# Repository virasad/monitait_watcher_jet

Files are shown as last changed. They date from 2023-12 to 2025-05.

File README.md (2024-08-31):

# Monitait Watcher Jet

Watcher Jet is an industrial Hardware to capture images and signals to use for monitoring and inspection manners, there are lots of applications which can be deployed by this without any concern about the power, UPS, freeze, hang, shocks and etc.
we have been working on it whithin 4 years and try to make it as reliable as possible beside having fixed security issues [Powered by Raspberry Pi](https://www.raspberrypi.com/for-industry/powered-by/product-catalogue/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)

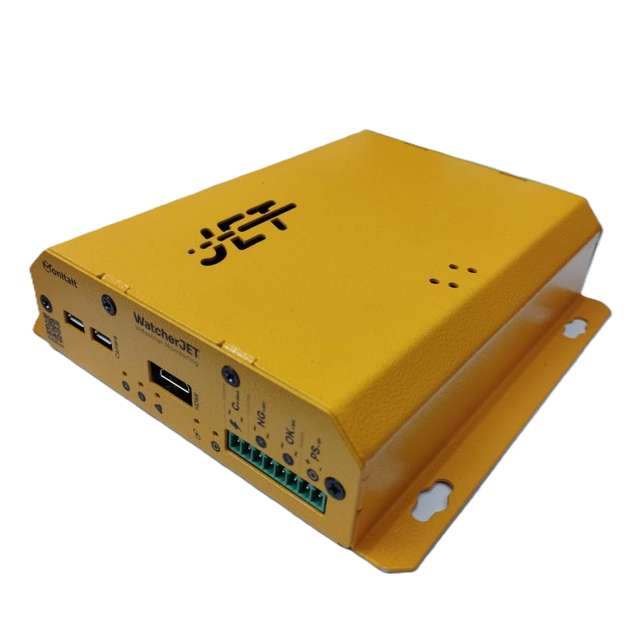
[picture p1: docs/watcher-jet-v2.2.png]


# Getting started

- if you have purchased Jet from Monitait just add it in [Watchers](https://console.monitait.com/factory/watchers) via the prepared REGISTER KEY under the box

- if you want to build watcher by youself follow the instruction in [initilize documentation](docs/README.md)

- need wiring and pinout? visit [Watcher Jet docs](https://monitait.com/docs)

- An external 12.6v 2A for `PS` (to recharge the internal battries, a regulated power is needed, polarity is important) 
- An Access Point with a SSID like: `monitait` and a password like: `p@ssword`
- Connect the Signals:
- a bipolar 12-24V digital signal for `OK`
- a bipolar 12-24V digital signal for `NG`
- a 4-20mA analog signal for `C`
- a USB camera for `CAMERA`
- a mini HDMI for `HDMI`

## Add watcher in your Monitait account

there is a register id for each watcher, add the register id in monitait console [Watchers](https://console.monitait.com/factory/watchers) tab

## Test and Deploy

- by Getting Digital Signals you should see blue indicators blink
- if the counting reached half of acceptable threshold, the warning red indicator will be turned on (in case of low battery as well)
- if the link between watcher and the server established, the red chain (link) inidactor blinks

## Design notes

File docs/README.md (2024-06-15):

# Monitait Watcher Jet

Watcher Jet is a set of an Arduino, a RaspberryPi Zero W and some Electorinc components with an internal UPS, to make sure the whole hardware and software of an Industrial monitoring application will work seamlessly



## How to initaite the RPI

- Wathcer jet heart is to make collabration between Arduino and RPI to have better data consitency
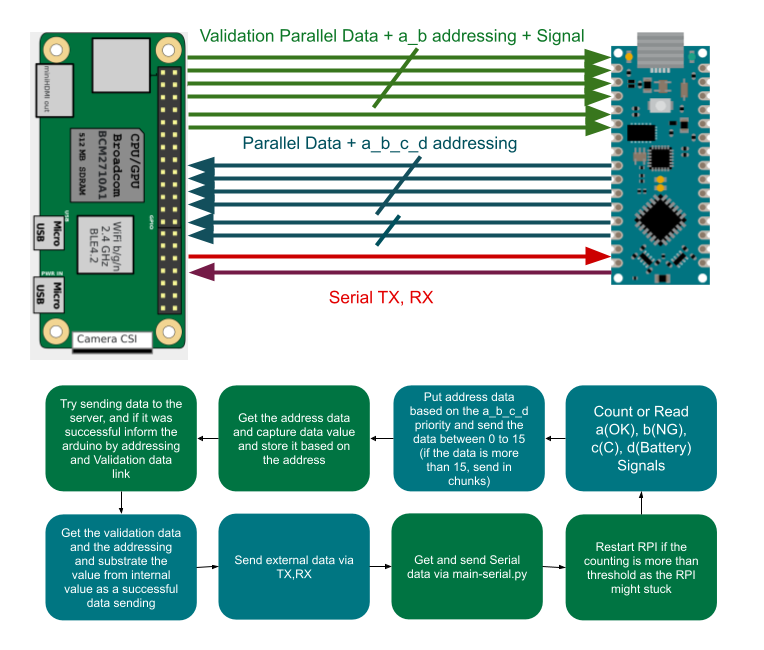
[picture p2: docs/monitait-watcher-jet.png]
monitait-watcher-jet-data-flow


- Order the PCB and the BOM of Watcher and solder all components on the board

- USE [Arduino IDE](https://www.arduino.cc/en/software) to upload the [jet-arduino](../jet-arduino/jet-arduino.ino) into the arduino board

- Install the [Raspberry Pi Imager](https://www.raspberrypi.com/software)

- Download and extract the [lite image](https://downloads.raspberrypi.com/raspios_lite_armhf/images/raspios_lite_armhf-2024-03-13/2024-03-12-raspios-bookworm-armhf-lite.img.xz)

- in the OS customisation Config page,set the name like `2024031501`(time + cronical number); set the user and password of rpi, the default user is `pi` and the default password is `raspberry`; the ssid and the password of the wireless network (i.e. `monitait` and `p@assword`) and in the SERVICES tab, enable the `SSH` (follow the instruction below)

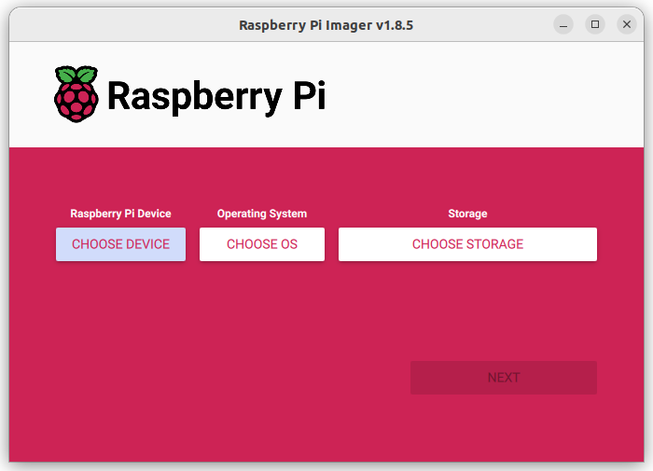
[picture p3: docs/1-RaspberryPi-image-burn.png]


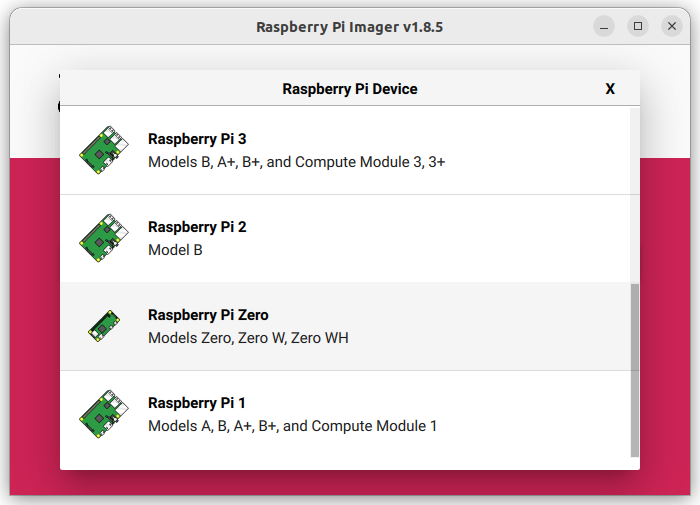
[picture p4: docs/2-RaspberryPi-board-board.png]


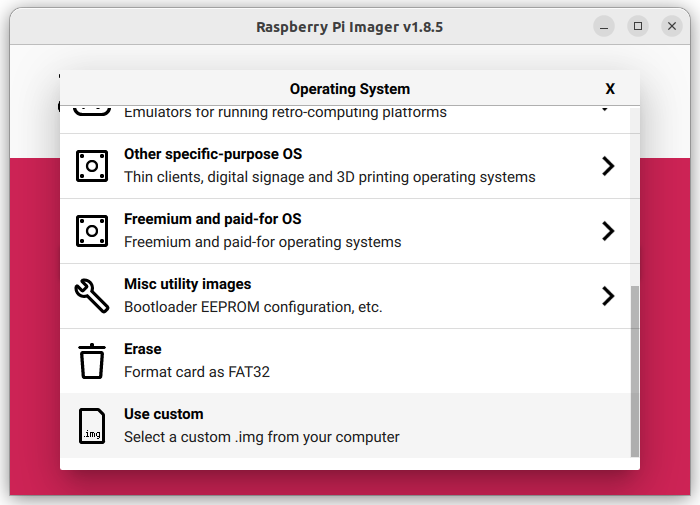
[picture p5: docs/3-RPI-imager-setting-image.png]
RPI-imager-setting


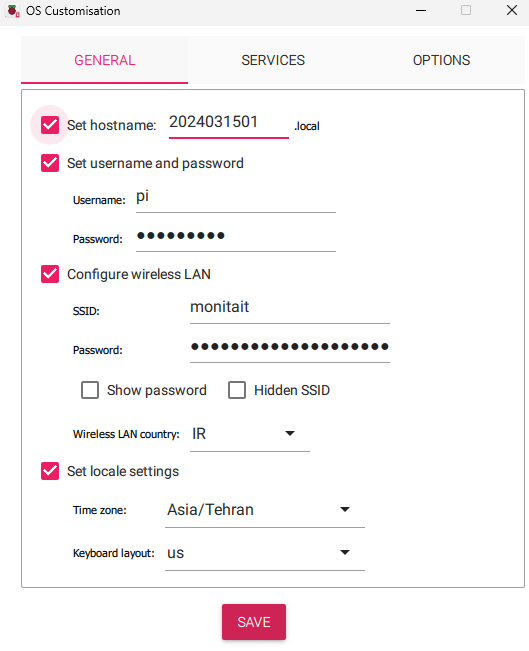
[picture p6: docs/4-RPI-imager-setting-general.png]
RPI-imager-setting


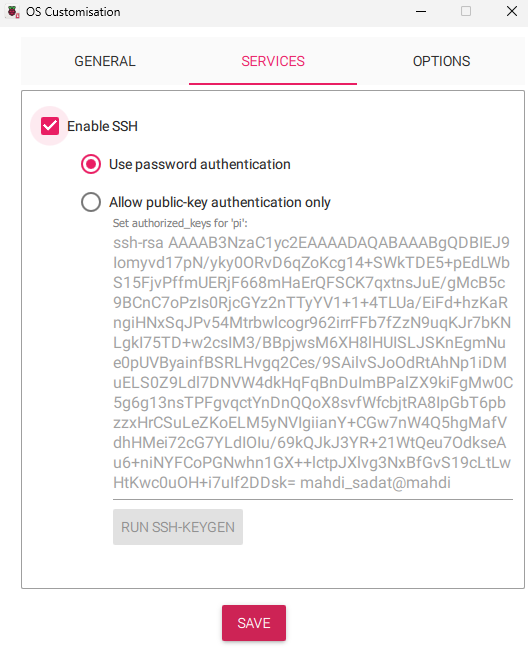
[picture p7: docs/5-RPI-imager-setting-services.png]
RPI-imager-setting


- Put the SD card in the RPI and wait for the RPI finish the setup
- ssh into rpi

`ssh pi@2024031501`

```
sudo apt-get install git -y
cd ~
git clone https://github.com/virasad/monitait_watcher_jet.git
bash /home/pi/monitait_watcher_jet/init/init.sh
sudo reboot now
```

What spare parts are needed to run on the watcher

- An SD card 
- An external 12.6v 2A for `PS` (to recharfe the internal battries, a regulated 12.6v power is needed)
- An Access Point with a SSID like: `monitait` and a password like: `p@ssword`
- a 12-24V digital signal for `OK`
- a 12-24V digital signal for `NG`
- a 4-20mA analog signal for `C`
- a USB camera for `CAMERA`
- a mini HDMI for `HDMI`

* the polarity only is important for PS

## Add watcher in your Monitait account

there is a register id for each watcher, add the register id in monitait console [Watchers](https://console.monitait.com/factory/watchers) tab

## Test and Deploy

- by sending Signals you should see blue indicators blink
- if the counting reached half of acceptable threshold, the warning red indicator will be turn on (in case of low battery as well)
- if the link between watcher and the server established, the link inidactor blinks

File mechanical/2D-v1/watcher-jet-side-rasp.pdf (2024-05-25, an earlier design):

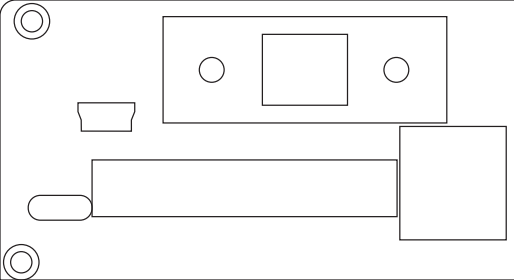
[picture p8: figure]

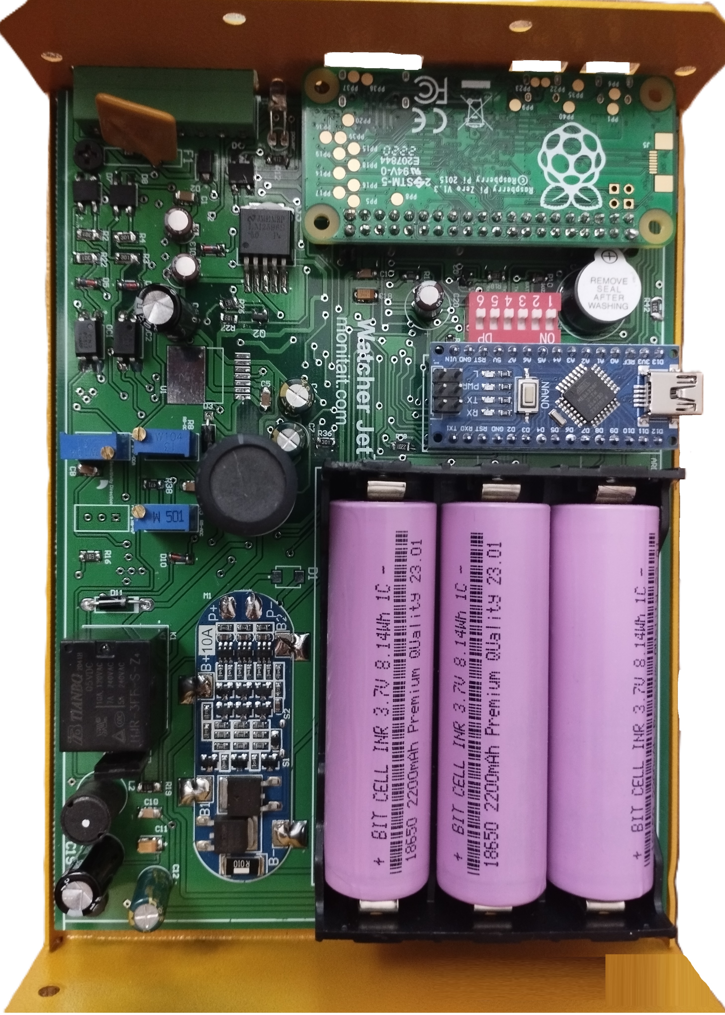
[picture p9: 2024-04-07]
docs/Jet-inside.jpg

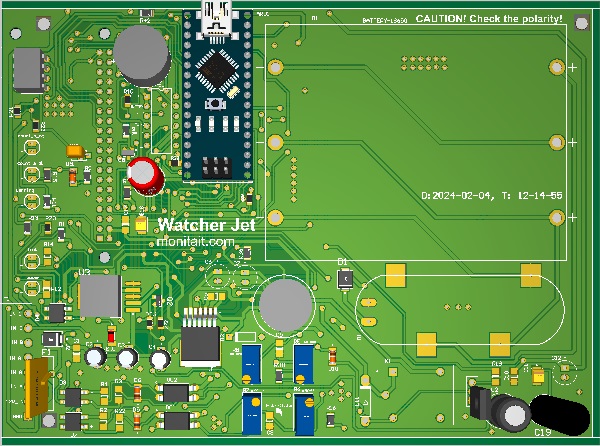
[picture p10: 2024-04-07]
pcb/PCB-v2/PCB-3D.jpg

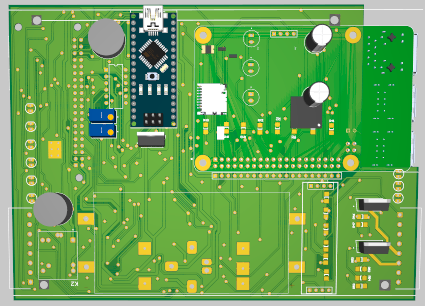
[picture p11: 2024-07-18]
pcb/Monitait_V2.png

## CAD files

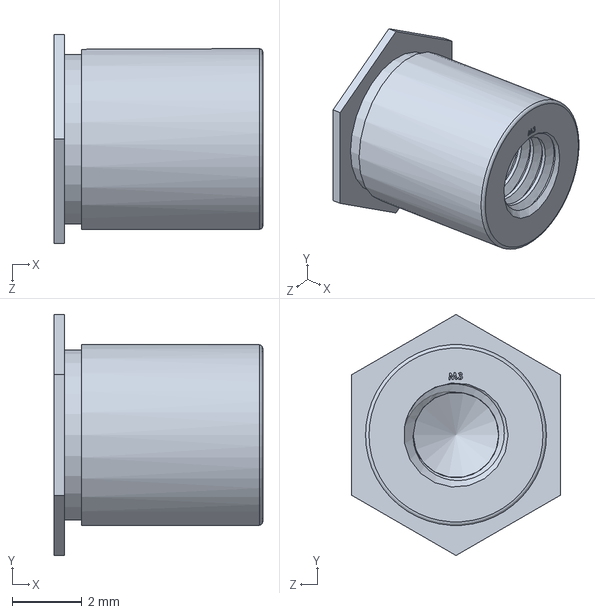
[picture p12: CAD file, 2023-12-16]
mechanical/3D-v3/M3 L6.SLDPRT
6.00 x 6.93 x 6.00 mm

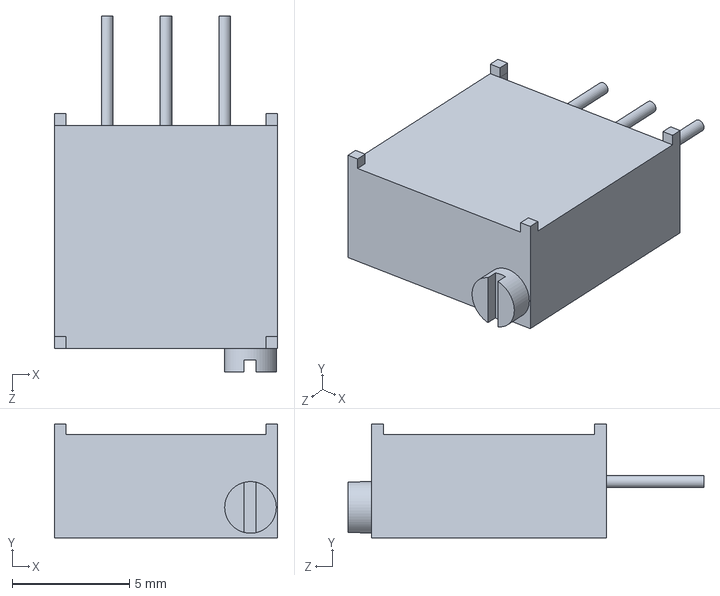
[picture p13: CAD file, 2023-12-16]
mechanical/3D-v3/Bourns-3296W.SLDPRT
9.50 x 4.85 x 15.1 mm

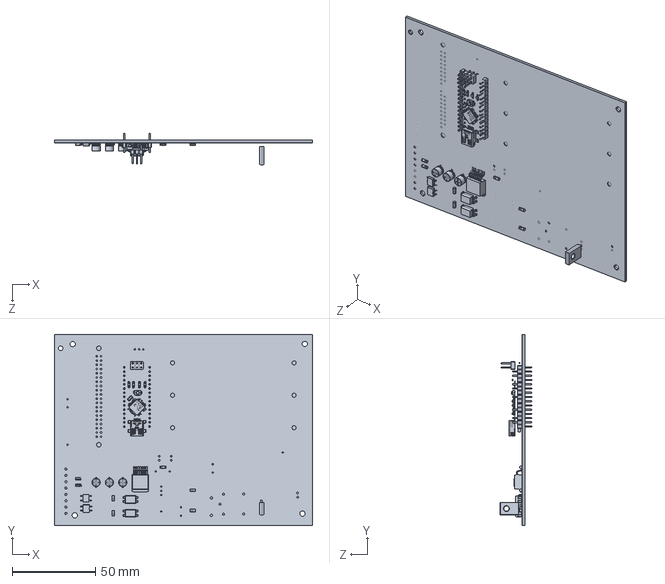
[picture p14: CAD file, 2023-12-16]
mechanical/3D-v3/Monitait_V2.SLDPRT
155.0 x 115.0 x 19.1 mm

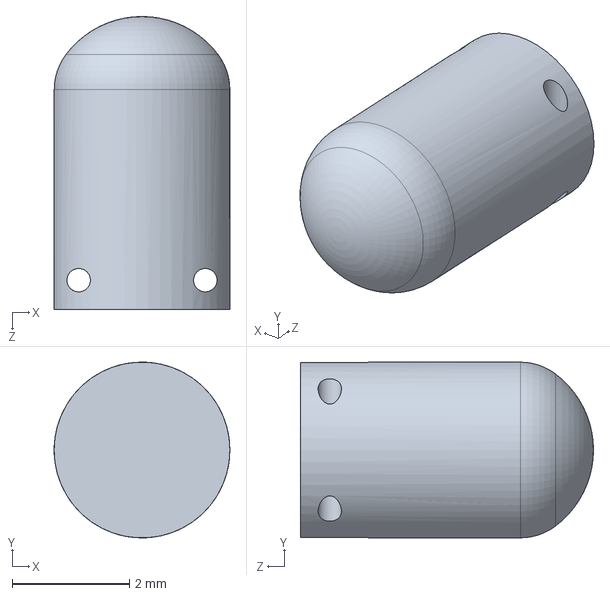
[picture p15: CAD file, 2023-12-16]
mechanical/3D-v3/LED 3.SLDPRT
3.00 x 3.00 x 5.00 mm

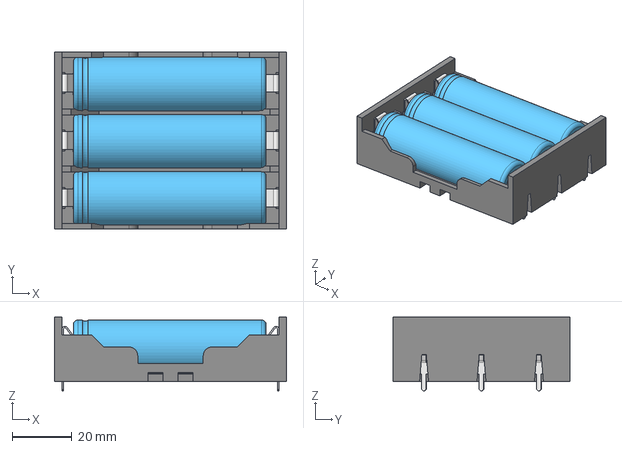
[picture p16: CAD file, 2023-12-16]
mechanical/3D-v3/3 Battery Holder With Batteries.step
78.0 x 59.6 x 24.7 mm

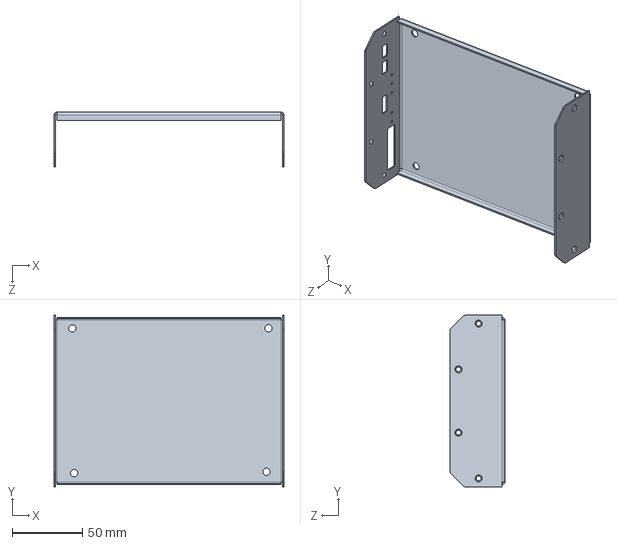
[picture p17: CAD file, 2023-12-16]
mechanical/3D-v3/Bottom Plate.SLDPRT
163.5 x 122.0 x 39.0 mm

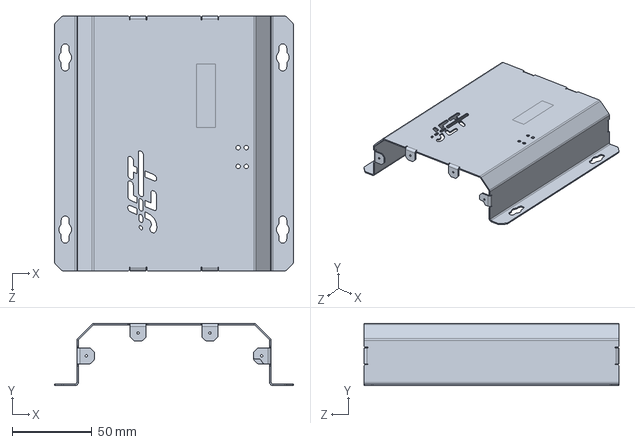
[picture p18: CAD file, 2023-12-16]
mechanical/3D-v3/Cover.SLDPRT
150.0 x 39.0 x 160.0 mm

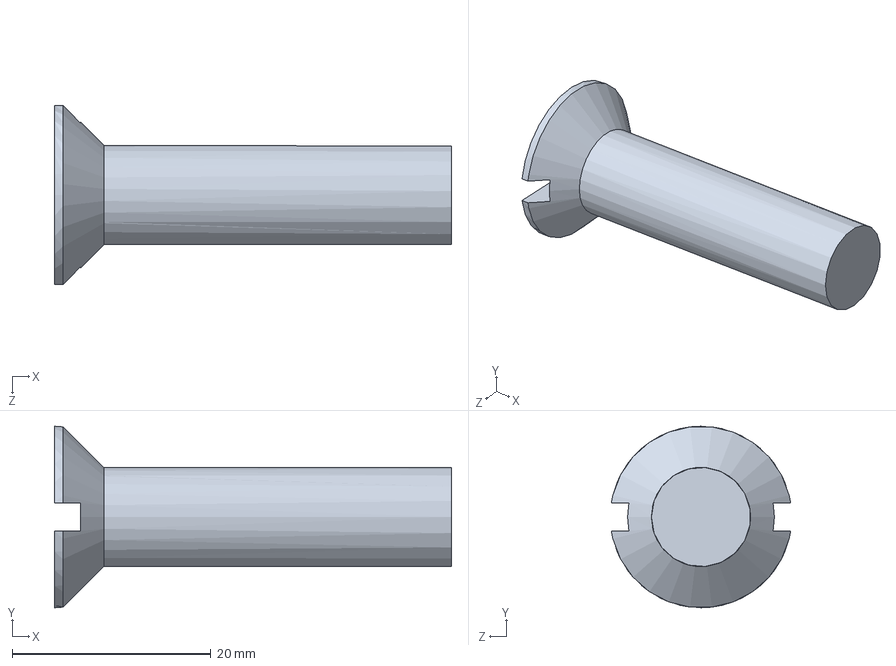
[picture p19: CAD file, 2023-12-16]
mechanical/3D-v3/flat head screw_am.sldprt
40.0 x 18.3 x 18.1 mm

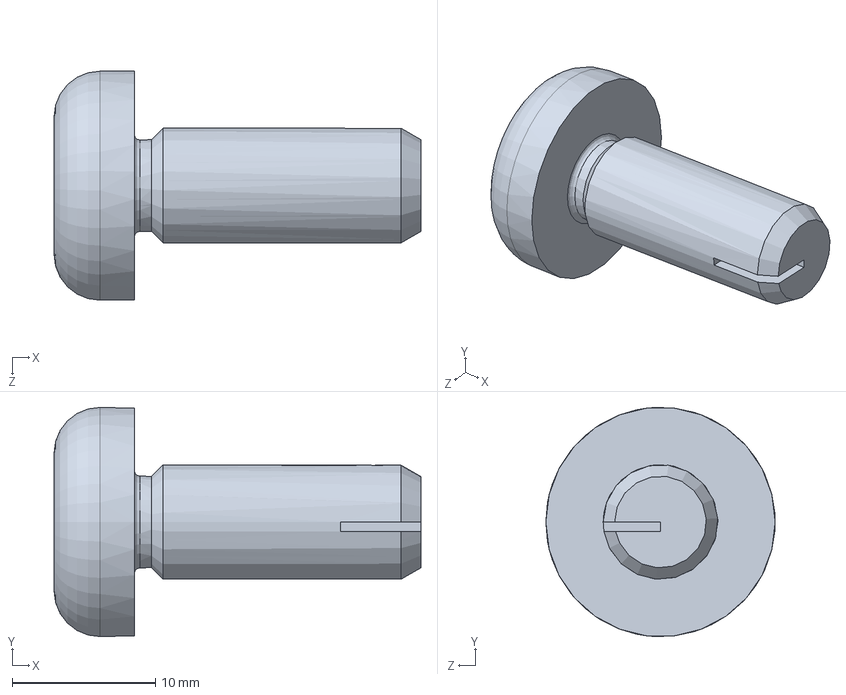
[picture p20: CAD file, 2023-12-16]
mechanical/3D-v3/pan head tapping screw_am.sldprt
25.6 x 16.0 x 16.0 mm

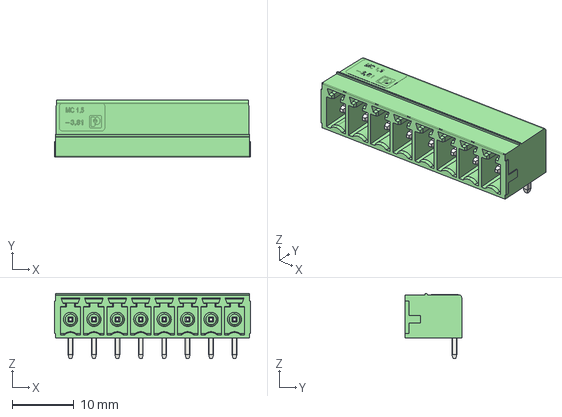
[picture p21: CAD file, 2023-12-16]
mechanical/3D-v3/1803332.stp
31.9 x 9.20 x 10.7 mm

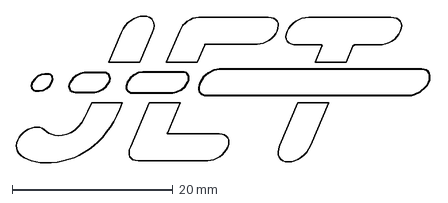
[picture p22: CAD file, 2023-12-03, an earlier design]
mechanical/2D-v1/monitait_engrave_watcher_jet_logo.dxf
51.8 x 18.3 mm

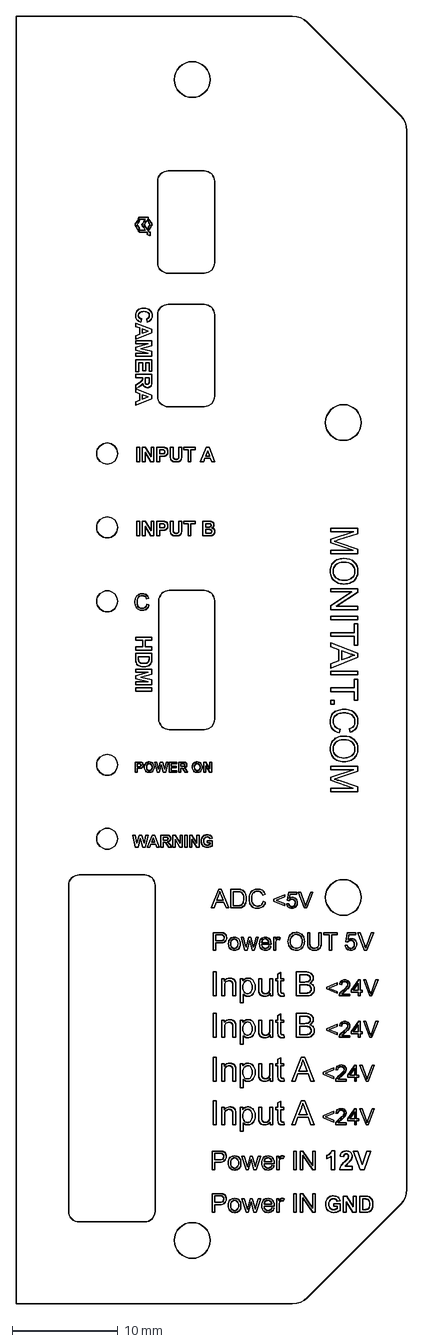
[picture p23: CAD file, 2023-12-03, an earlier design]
mechanical/2D-v2.1/jet.dxf
37.0 x 122.0 mm

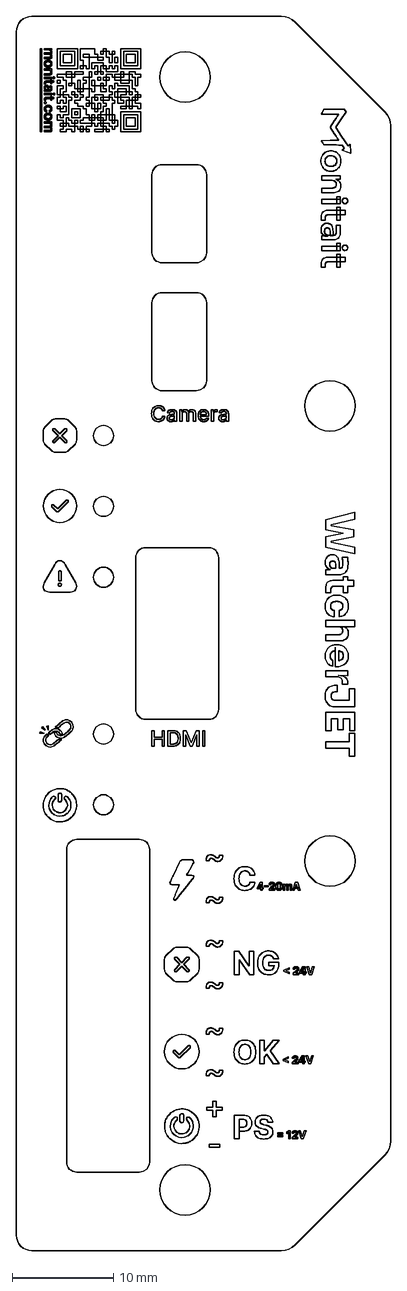
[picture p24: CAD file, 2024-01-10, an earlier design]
mechanical/2D-v2.2/watcher-jet-v2.2-side-layout.dxf
37.0 x 122.0 mm

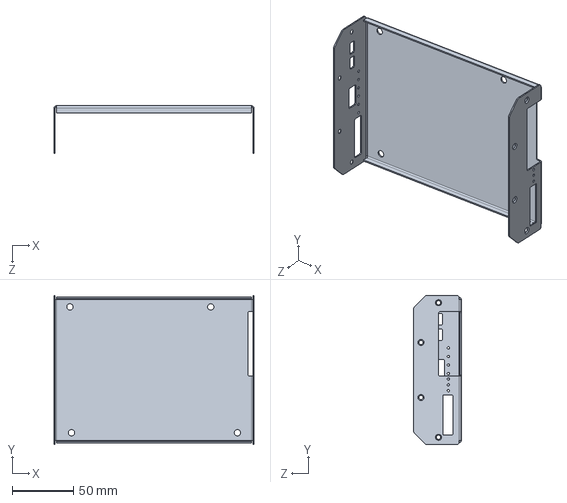
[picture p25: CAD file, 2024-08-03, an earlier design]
mechanical/3D/Bottom Plate_Ver2.SLDPRT
163.5 x 122.0 x 39.0 mm

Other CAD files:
mechanical/3D-v3/MirrorBourns-3296W.SLDPRT
mechanical/3D-v3/Logo.SLDPRT
mechanical/3D-v3/1803332.SLDPRT
mechanical/3D-v3/3 Battery Holder With Batteries.SLDPRT
mechanical/3D-v3/Watcher JET Assy.SLDDRW
mechanical/3D/Cover_Ver2.SLDPRT
mechanical/3D/Logo_Ver2.SLDPRT
mechanical/3D/countersunk flat head cross recess screw_din.sldprt

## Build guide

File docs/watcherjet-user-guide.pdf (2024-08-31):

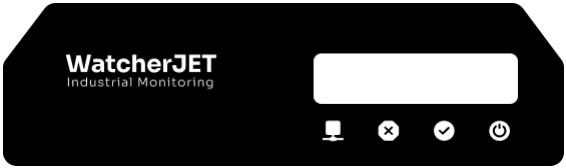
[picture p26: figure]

Step 1: | Step 2:
Connect the sensors | Connect the power supply
Step 3:
Provide an
access point
AP
Step 4:
Go to onsole.monitait.com/factory/watchers to add your watcher and get real-time feedback

# WatcherJET 3.0

# STEP-BY-STEP USER GUIDE

monitait.com | Powered by Monitait

WatcherJET 3.0

USER GUIDE
Table of Contents
Step 1: Connect the sensors
External machine signal

Mode settings for counting defects

Push button

Obstacle sensor

Encoder

Step 2: Connect the power supply

Power supply specifications

Step 3: Provide an access point

Access point setup

Step 4: Go to console.monitait.com

Software setup

Chapter 1: Collecting data

USER GUIDE
Table of Contents

Chapter 2: Taking action

Step 1: Connect the high current power supply High current power supply
Step 2: Set up the emitters

Connecting the emitters

Step 3: Connect the actuators

Ejector and warning

USER GUIDE
1
Step 1: Connect the sensors

External machine signal

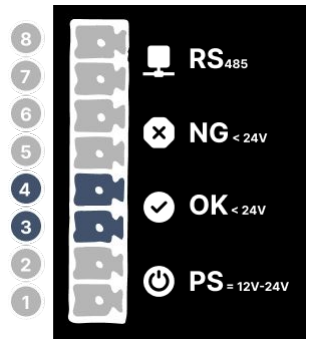
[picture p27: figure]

- Production Count

Any 1224 signal from the machine can be used as a one piece counter. Connect 2 wires from your machine to the OK inputs 3 and 4) to start counting automatically with WatcherJET.

Bidirectional signal and isolated by internal optocoupler

ejector signal, ensure that keys 3 and 4

- Counting Defects

Connect the ejector signal or the machine output to the NG inputs 5 and 6.

DATASHEET Step 1: Connect the sensors

External machine signal

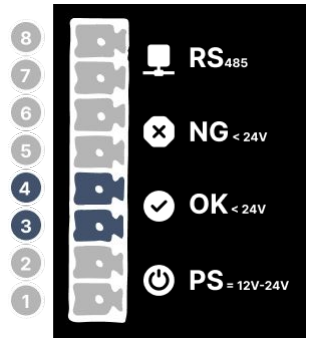
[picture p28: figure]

- Production Count

Any 1224 signal from the machine can be used as a one piece counter. Connect 2 wires from your machine to the OK inputs 3 and 4) to start counting automatically with WatcherJET.

Bidirectional signal and isolated by internal optocoupler

- Counting Defects

Connect the ejector signal or the machine output to the NG inputs 5 and 6.

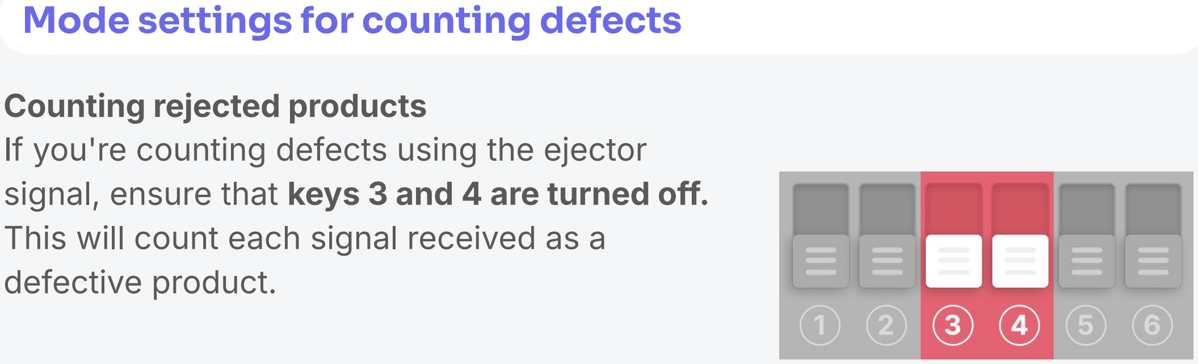
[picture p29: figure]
Counting rejected products; defective product.; Mode settings for counting defects

If you're counting defects using the ejector signal, ensure that keys 3 and 4 are turned off. This will count each signal received as a

DATASHEET Step 1: Connect the sensors

Counting remained products

If you're counting non-defective products based on the machine output signal, turn key 3 on and key 4 off. This will count the remaining products after subtracting the defective ones Total OK products minus NG products).

Push button

- Production Count

Take one wire from the push button and connect it to the OK input 4. Connect the

other wire from the same button to the negative power input 1.

Now, take a wire and connect the other OK input 3) to the positive power input 2.

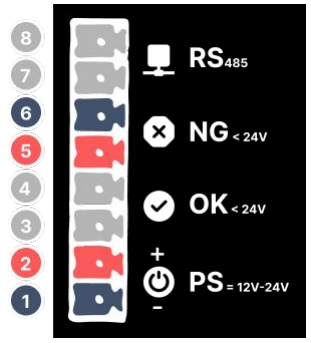
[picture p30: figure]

- Counting Defects

To count defects with a push button repeat the same steps with another push button and the NG inputs.

Take one wire from the push button and connect it to the NG input 6. Connect the other wire from the same button to the negative power input 1.

DATASHEET Step 1: Connect the sensors

Now, take a wire and connect the other NG input 5) to the positive power input 2.

Obstacle sensor

- Production Count

Take the sensor black wire and connect it to the OK input 4. Then connect the brown wire to the positive power input 2 and the blue wire to the negative power input 1.

Now, take a wire and connect the other OK input 3) to the positive power input 2.

- Counting Defects

To count defects with a obstacle sensor repeat the same steps with another sensor and the NG inputs. Then adjust the mode settings according to your counting method.

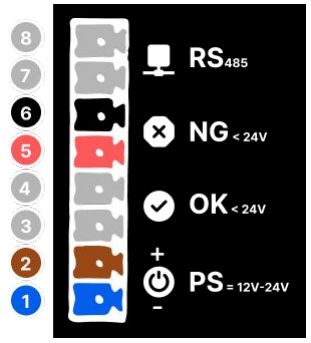
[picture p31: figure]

Take the sensor black wire and connect it to the NG input 6. Then connect the brown wire to the positive power input 2 and the blue wire to the negative power input 1.

Now, take a wire and connect the other NG input 5) to the positive power input 2.

DATASHEET Step 1: Connect the sensors

Encoder

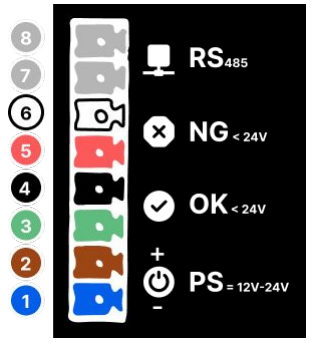
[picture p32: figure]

Take the encoder white wire and connect it to one of the NG inputs 6. Then take the black wire and connect it to the OK input 4. Now, connect the brown wire to the positive power input 2 and the blue wire to the negative power input 1.

Finally take two wires and connect the other OK input 3) and the other NG input 5) to the positive power input 2.

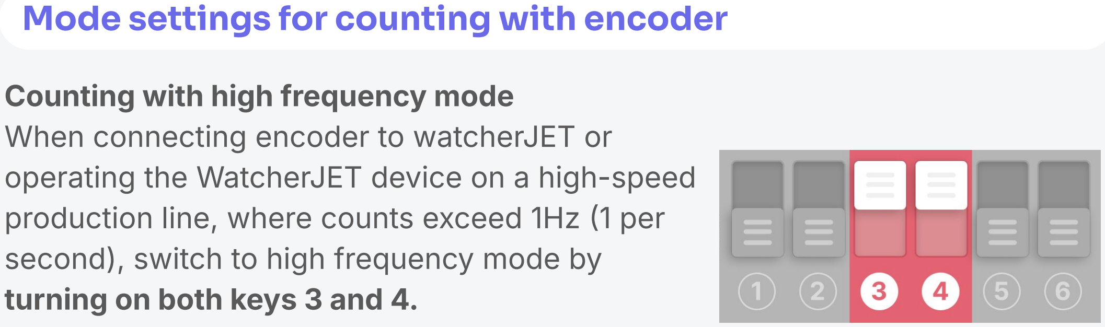
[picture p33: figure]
Counting with high frequency mode; turning on both keys 3 and 4.; Mode settings for counting with encoder

When connecting encoder to watcherJET or operating the WatcherJET device on a high-speed production line, where counts exceed 1Hz 1 per second), switch to high frequency mode by

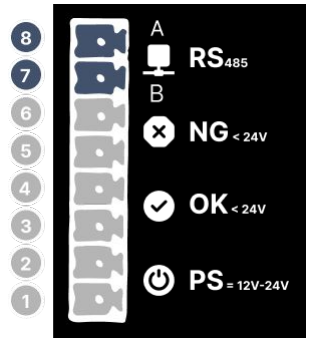
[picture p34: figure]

RS485 protocol

If you want to connect more than one sensor to your device and collect other types of data you need to use RS485 protocol. Take the A lead from your sensor and connect it to the RS485A inputs 8) then take the B lead of the sensor and connect it to the RS485B inputs 7.

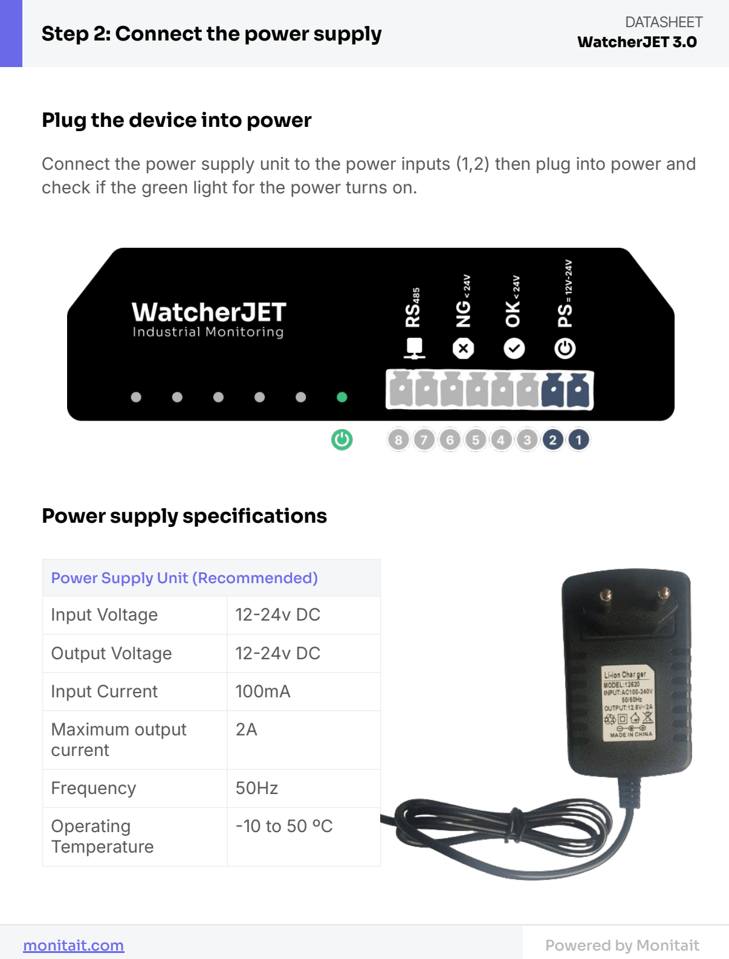
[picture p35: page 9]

DATASHEET Step 2: Connect the power supply

Plug the device into power

Power Supply Unit (Recommended)
Input Voltage | 1224v DC
Output Voltage | 1224v DC
Input Current | 100mA
Maximum output current | 2A
Frequency | 50Hz
Operating Temperature | 10 to 50 ºC

Connect the power supply unit to the power inputs 1,2) then plug into power and check if the green light for the power turns on.

Power supply specifications

DATASHEET Step 3: Provide an access point

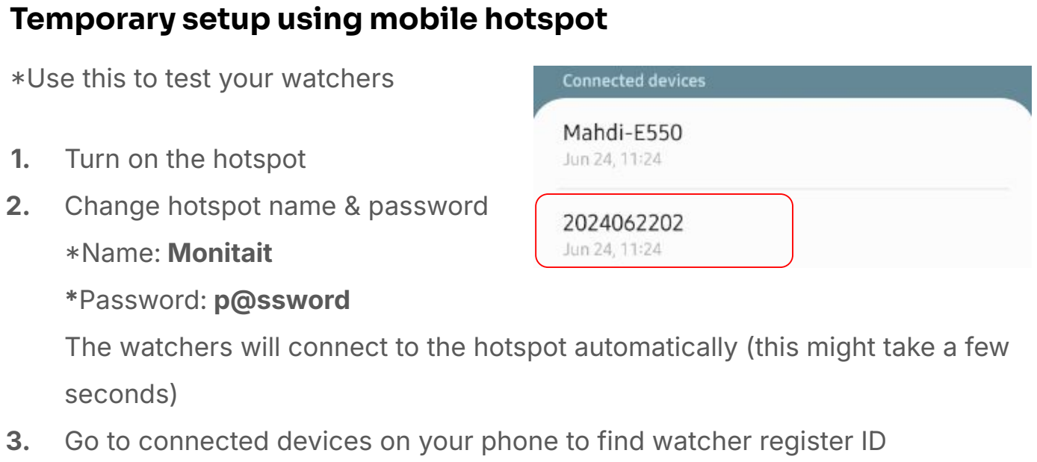
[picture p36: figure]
Temporary setup using mobile hotspot; 1. Turn on the hotspot 2. Change hotspot name & password Name: Monitait *Password: p@ssword; seconds); Use this to test your watchers

The watchers will connect to the hotspot automatically (this might take a few

### 3. Go to connected devices on your phone to find watcher register ID

Permanent setup using router

You can use any type of router you have for this step but if you are considering acquiring new ones there are three models that have been tested and completely compatible with WatcherJET system:

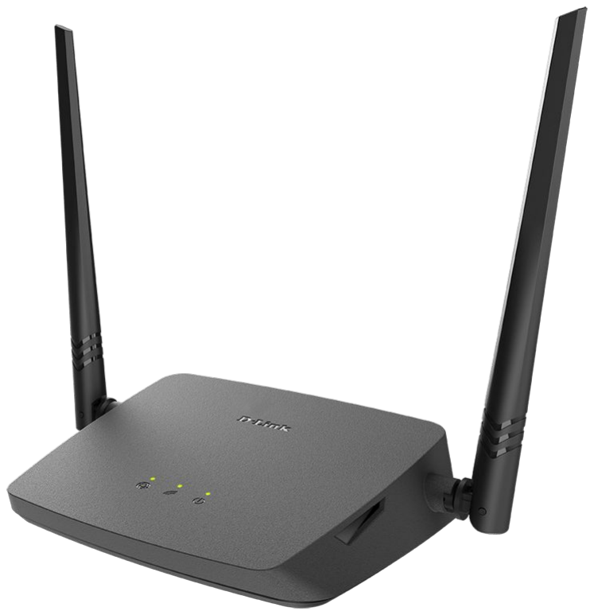
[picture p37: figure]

Tenda N301 - setup (https://www.tendacn.com/product/overview/N301.html)
DLink DIR612 - setup (https://www.dlink.com/middle-east/en/products/dir-612-wireless-n300-router)
UniFi APACLR - setup (https://dl.ubnt.com/guides/UniFi/UniFi_AP-AC-LR_QSG.pdf)

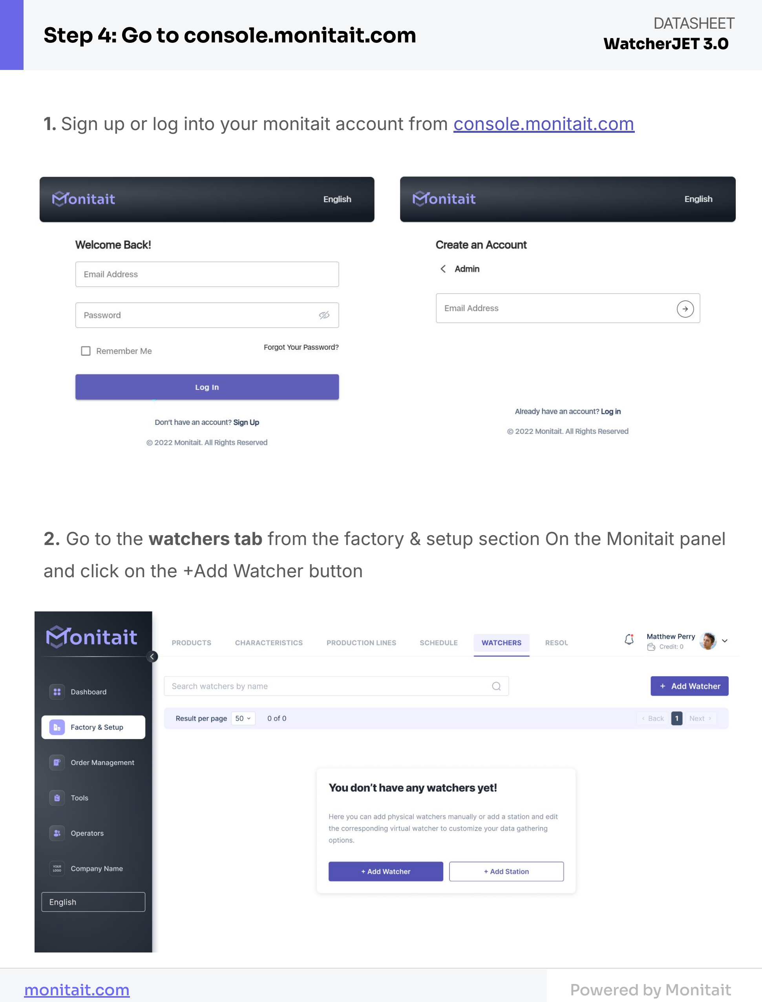
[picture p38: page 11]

DATASHEET Step 4: Go to console.monitait.com

### 1. Sign up or log into your monitait account from console.monitait.com

### 2. Go to the watchers tab from the factory & setup section On the Monitait panel

and click on the Add Watcher button

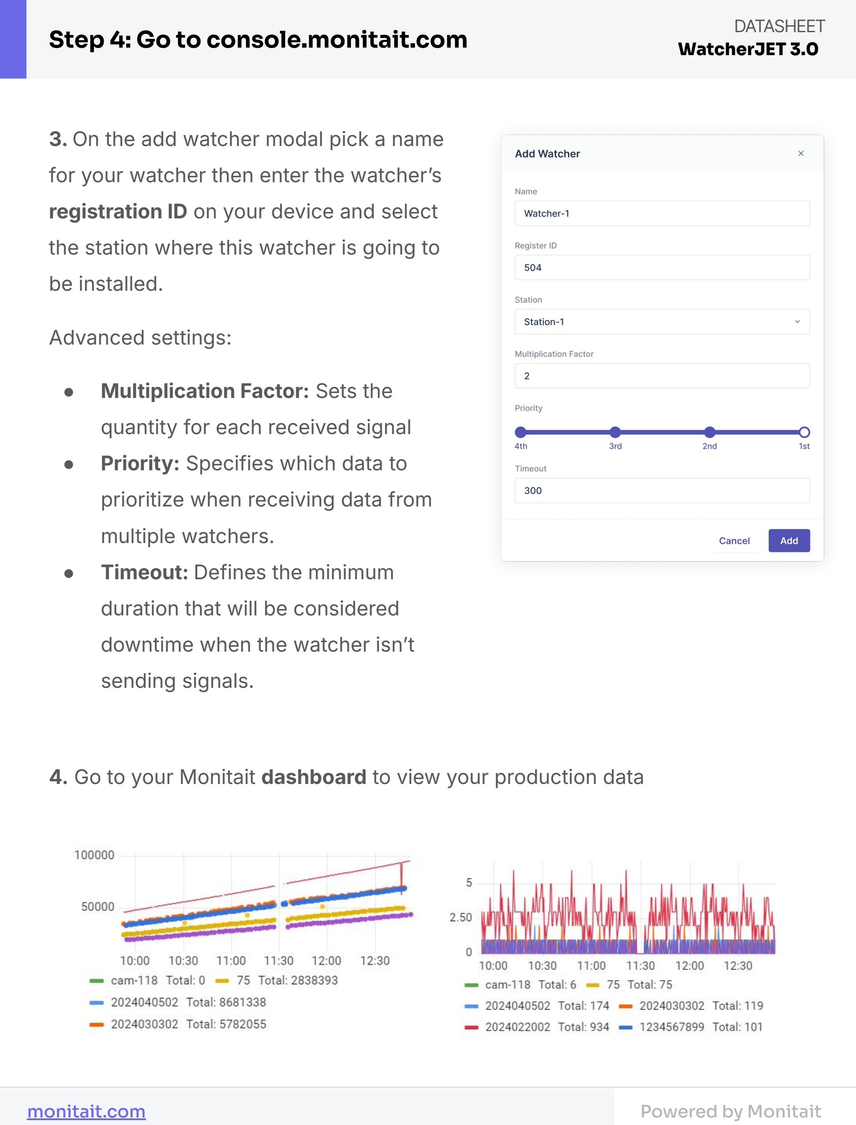
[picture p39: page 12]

DATASHEET Step 4: Go to console.monitait.com

### 3. On the add watcher modal pick a name

for your watcher then enter the watcherʼs registration ID on your device and select the station where this watcher is going to be installed.

Advanced settings:

- Multiplication Factor: Sets the quantity for each received signal
- Priority: Specifies which data to prioritize when receiving data from multiple watchers.
- Timeout: Defines the minimum duration that will be considered downtime when the watcher isnʼt sending signals.

### 4. Go to your Monitait dashboard to view your production data

DATASHEET Step 1: Connect the high current power supply

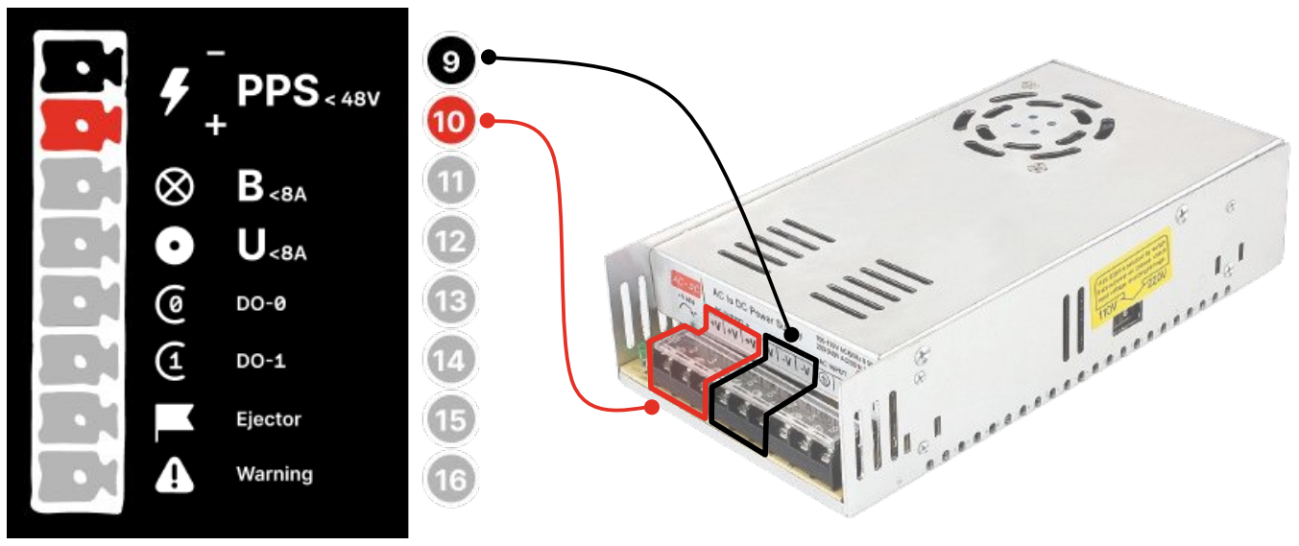
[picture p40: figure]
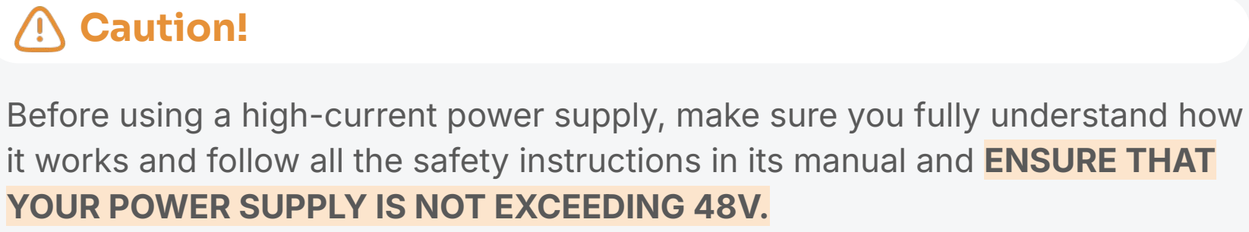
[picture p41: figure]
YOUR POWER SUPPLY IS NOT EXCEEDING 48V.; Caution!

Before using a high-current power supply, make sure you fully understand how it works and follow all the safety instructions in its manual and ENSURE THAT

- Take a wire and connect one of the negative power supply outputs to the negative PPS input on the watcher 10.
- Take another wire and connect one of the positive power supply outputs to the positive PPS input on the watcher 9.

DATASHEET Step 2: Set up the emitters

Connecting the emitters

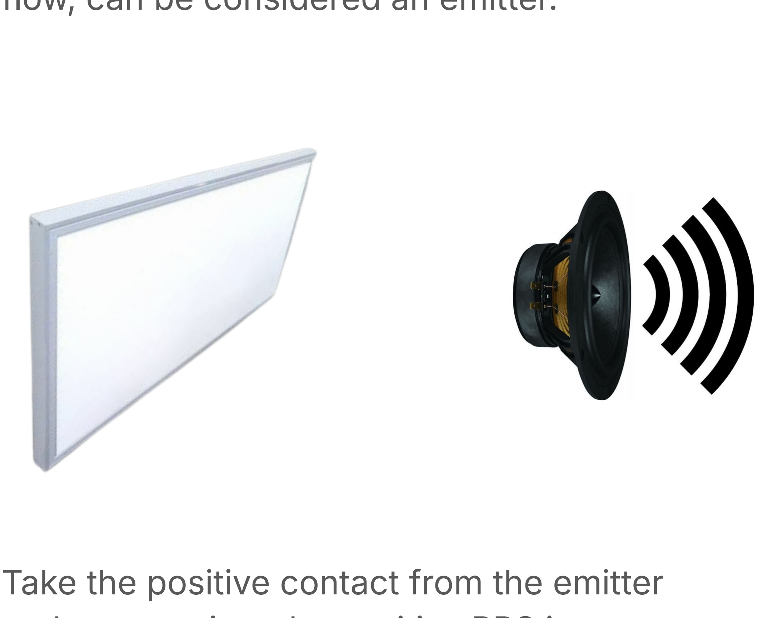
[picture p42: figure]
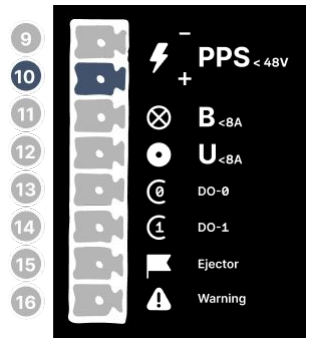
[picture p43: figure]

Take the positive contact from the emitter and connect it to the positive PPS input on the watcher 10.

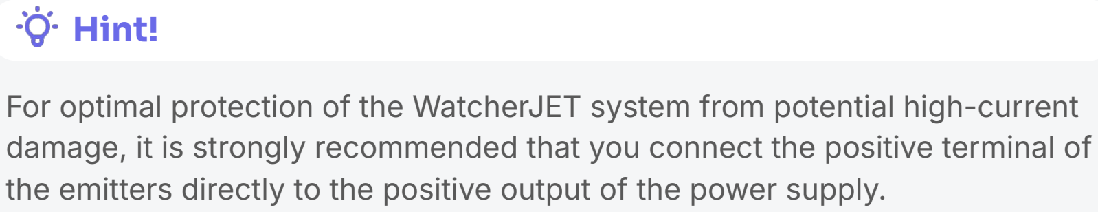
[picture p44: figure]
Hint!

For optimal protection of the WatcherJET system from potential high-current damage, it is strongly recommended that you connect the positive terminal of the emitters directly to the positive output of the power supply.

Any device or component that generates and releases a specific type of signal, such as light, sound, or electromagnetic waves, projecting it in an unidirectional flow, can be considered an emitter.

DATASHEET Step 2: Set up the emitters

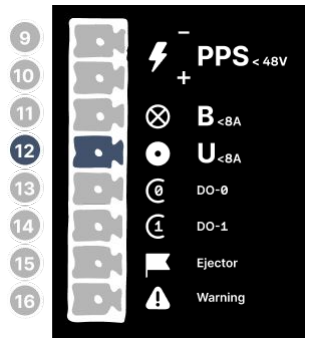
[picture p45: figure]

- Aligned Emitters: If the emitters are positioned side by side and in close proximity to the detector, they are considered to be ‘alignedʼ. In this case take the negative contact from the emitter and connect it to the U output 12 on the watcher.

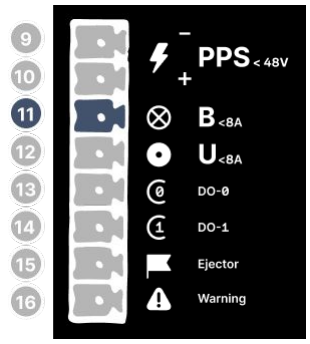
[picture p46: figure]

- Adverse Emitters: If the emitters are placed far from the detector and their signal comes from the other side they are considered to be ‘adverseʼ. In this case take the negative contact from the emitter and connect it to the B output 11 on the watcher.

The rest of this process depends on the emitter intended placement:

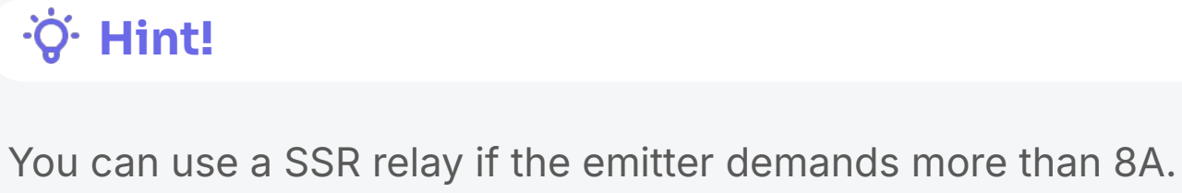
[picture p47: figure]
Hint!

You can use a SSR relay if the emitter demands more than 8A.

DATASHEET Step 3: Connect the actuators

Digital Outputs

DO0 and DO1 13 and 14) are digital outputs and they need advanced settings.
Contact our technical team to learn more about these outputs.

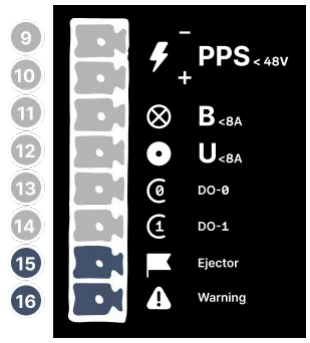
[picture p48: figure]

Connecting ejector and warning

To take action based on the collected data you can connect the ejector 15) and warning 16) outputs to your PLC digital input.

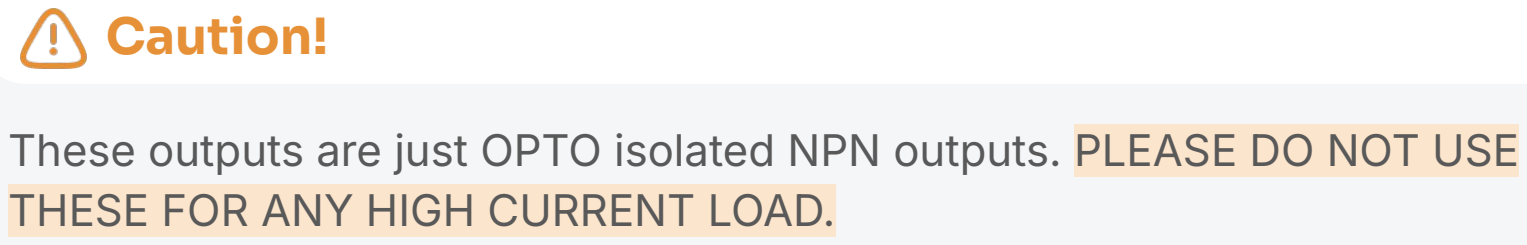
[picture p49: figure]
THESE FOR ANY HIGH CURRENT LOAD.; Caution!

These outputs are just OPTO isolated NPN outputs. PLEASE DO NOT USE

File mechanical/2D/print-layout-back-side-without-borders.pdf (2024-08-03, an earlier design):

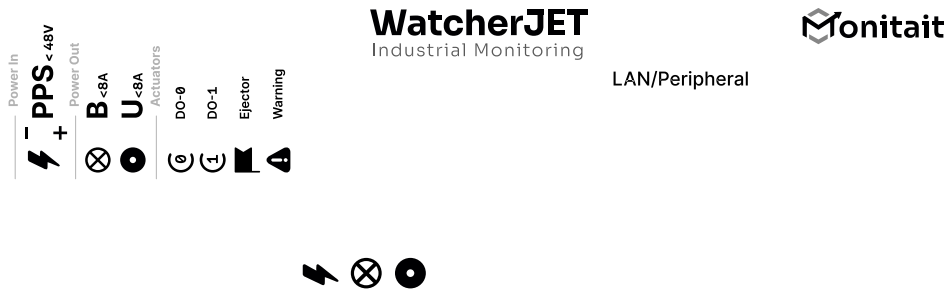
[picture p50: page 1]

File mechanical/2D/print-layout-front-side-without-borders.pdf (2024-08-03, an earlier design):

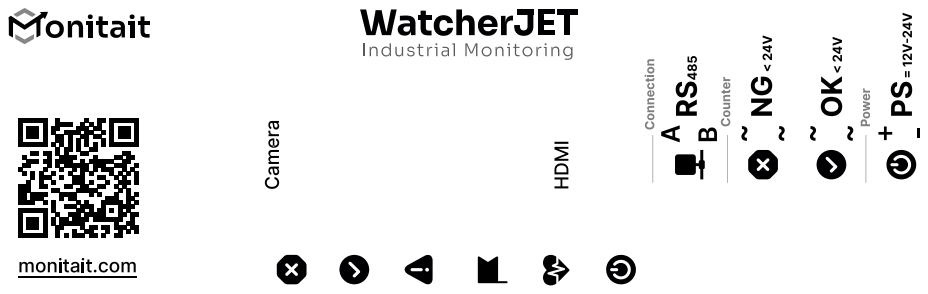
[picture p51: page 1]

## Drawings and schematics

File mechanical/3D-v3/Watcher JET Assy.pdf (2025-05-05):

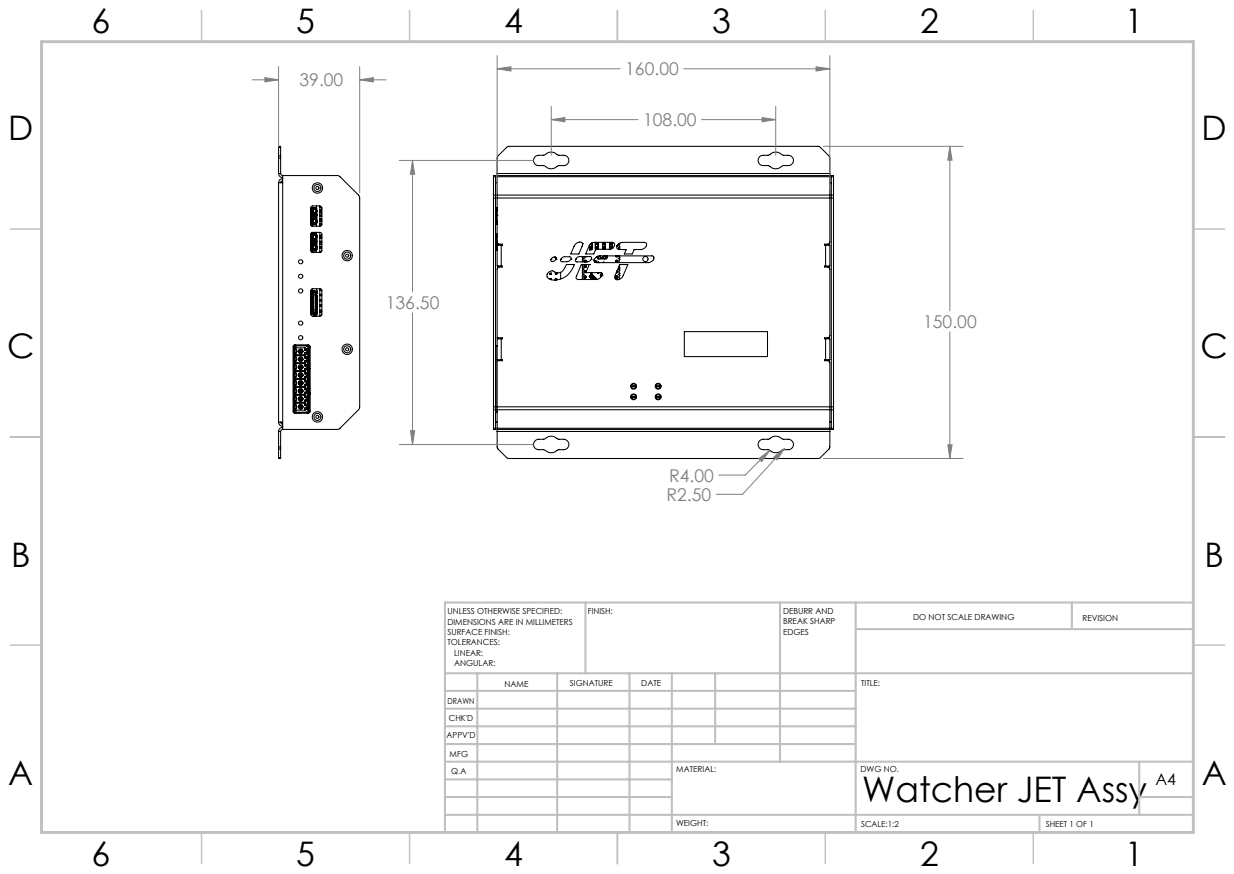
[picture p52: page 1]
FINISH:; DEBURR AND; BREAK SHARP; DO NOT SCALE DRAWING; REVISION; SCALE:1:2; SHEET 1 OF 1

UNLESS OTHERWISE SPECIFIED:
DIMENSIONS ARE IN MILLIMETERS
SURFACE FINISH:
TOLERANCES:
LINEAR:
ANGULAR:

NAME | SIGNATURE | DATE | | | | TITLE:

DRAWN
CHK'D
APPV'D
MFG
Q.A | | | | MATERIAL: | DWG NO. Watcher JET Assy | A4

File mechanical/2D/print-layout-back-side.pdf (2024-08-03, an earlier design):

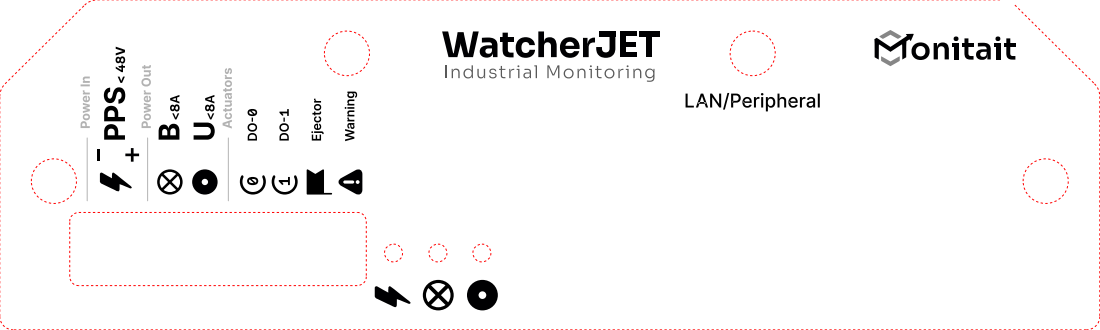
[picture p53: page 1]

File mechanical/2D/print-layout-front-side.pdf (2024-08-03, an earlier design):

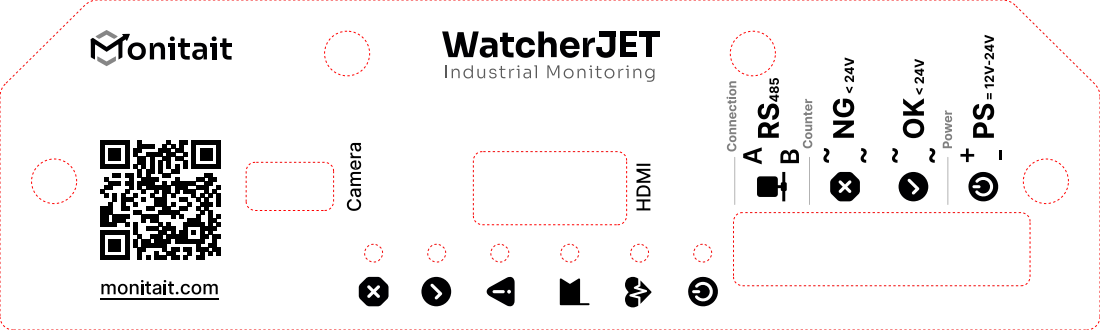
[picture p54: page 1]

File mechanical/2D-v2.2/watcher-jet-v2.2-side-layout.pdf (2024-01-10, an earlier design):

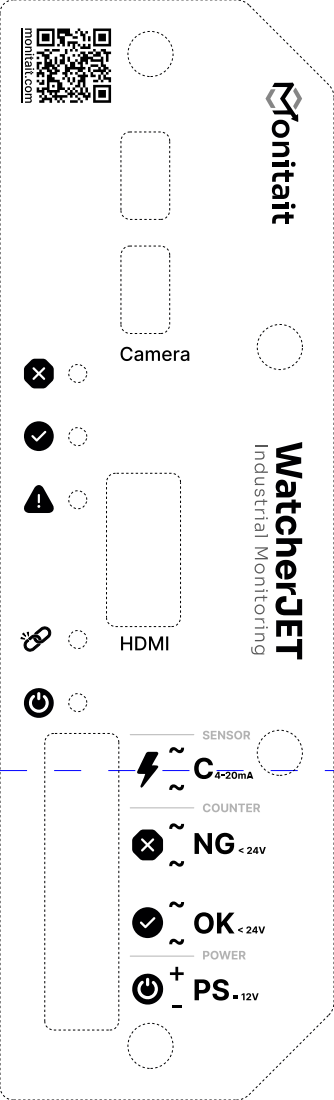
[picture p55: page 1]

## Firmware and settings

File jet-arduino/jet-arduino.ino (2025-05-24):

#include <avr/wdt.h>
#include <EEPROM.h>

// read documenation of indicators and the watcher in https://monitait.com/docs

// Timing constants
const unsigned long TWO_MS_PULSES = 125;  // 125 pulses per 2 milliseconds
const unsigned long TEN_MS_PULSES = 625;  // 625 pulses per 10 milliseconds
const unsigned long ONE_SEC_PULSES = TEN_MS_PULSES * 100; // Number of pulses in one second
const unsigned long ONE_MIN_PULSES = ONE_SEC_PULSES * 60;   // 3,750,000 pulses per minute

// Restart interval (1 minute = 60 * 62500 = 3,750,000 pulses)
const unsigned long MIN_RESTART_INTERVAL = ONE_MIN_PULSES;

// Global timing variables
unsigned long current_time = 0;  // Current time in milliseconds
unsigned long ok_last_check_time = 0;  // Last check time for OK signal
unsigned long ng_last_check_time = 0;  // Last check time for NG signal
unsigned long last_speed_calc_time = 0;  // Last time speed was calculated
unsigned long last_speed_calc_minute_time = 0;  // Last time minute speed was calculated
unsigned long last_heartbeat_time = 0;  // Last time heartbeat LED was updated

// Debounce counters
unsigned int ok_high_count = 0;  // Counter for OK signal high state
unsigned int ng_high_count = 0;  // Counter for NG signal high state

// Serial communication
String inString = "";  // Buffer for serial input

// Input pins
const byte PIN_OK_INPUT = 2;      // OK signal input
const byte PIN_NG_INPUT = 3;      // NG signal input
const byte PIN_U_OUTPUT = 6;      // U direction output
const byte PIN_B_OUTPUT = 5;      // B direction output
const byte PIN_RPI_SIGNAL = 11;   // RPI communication signal
const byte PIN_RPI_ADDRESS = 18;  // RPI address selection
const byte PIN_WARNING_LED = 10;  // Warning LED indicator
const byte PIN_HEARTBEAT_LED = 13;// Heartbeat LED indicator
const byte PIN_RPI_RESET = 12;    // RPI reset control
const byte PIN_OK_IDENTIFIER = 8; // OK status indicator
const byte PIN_NG_IDENTIFIER = 9; // NG status indicator

// RPI communication pins
const byte PIN_RPI_DATA_IN[3] = {
  14, 15, 16
}; // RPI data input pins

const byte PIN_RPI_DATA_OUT[3] = {
  4, 7, 17
}; // RPI data output pins

long counter_ok = 0;
long counter_ng = 0;
long encoder_counter = 0;
unsigned int battery;
unsigned int analog = 0;
unsigned int counter_rpi_reboot = 1000;
unsigned int restart_counter = 1;
long counter_sum_ok_ng = 0;
unsigned long elapsed_speed = 100;
unsigned long last_pi_ping_time;
int pwmup = 255;
int pwmdown = 255;

byte output_status = 0; // Store real-time output state

byte get_byte;
byte out_pins_number;

volatile long last_encoder_count = 0;
long pulse_sec_speed = 0;

volatile long last_encoder_count_minute = 0;
long pulse_min_speed = 0;

volatile long downtime_seconds = 0;
int downtime_threshold = 10;
void(* resetFunc) (void) = 0;
#define EEPROM_PRINT_MODE 0        // 0-3: Print mode (0 for new, 1 for legacy)
#define EEPROM_VERBOSE_MODE 4      // 4-7: Verbose mode (0 for off, 1 for on)
#define EEPROM_EXT_RESET_ENABLED 8 // 8-11: External reset enabled (0 for off, 1 for on)
#define EEPROM_OK_OFFSET_DELAY 12  // 12-15: OK offset delay in pulses
#define EEPROM_OK_DEBOUNCE_PULSE 16 // 16-19: OK debounce pulse count
#define EEPROM_OK_DEBOUNCE_PERCENT 20 // 20-23: OK debounce percent
#define EEPROM_OK_ENCODER_FACTOR 24 // 24-27: OK encoder factor
#define EEPROM_NG_OFFSET_DELAY 28  // 28-31: NG offset delay in pulses
#define EEPROM_NG_DEBOUNCE_PULSE 32 // 32-35: NG debounce pulse count
#define EEPROM_NG_DEBOUNCE_PERCENT 36 // 36-39: NG debounce percent
#define EEPROM_NG_ENCODER_FACTOR 40 // 40-43: NG encoder factor
#define EEPROM_DOWNTIME_THRESHOLD 44 // 44-47: Downtime threshold
#define EEPROM_BAUD_RATE 48        // 48-51: Baud rate

// Default baud rate if EEPROM is empty
#define DEFAULT_BAUD_RATE 57600

// Convert milliseconds to pulses
#define MS_TO_PULSES(ms) (((ms) * TWO_MS_PULSES) / 2)
// Convert pulses to milliseconds
#define PULSES_TO_MS(pulses) ((pulses) * 2 / TWO_MS_PULSES)

// Default delay values in milliseconds
#define DEFAULT_OFFSET_DELAY_MS 0
#define DEFAULT_DEBOUNCE_PULSE 10
#define DEFAULT_DEBOUNCE_PERCENT 60

unsigned long ok_offset_delay = MS_TO_PULSES(DEFAULT_OFFSET_DELAY_MS);
unsigned long ok_debounce_pulse = DEFAULT_DEBOUNCE_PULSE;
unsigned long ok_debounce_percent = DEFAULT_DEBOUNCE_PERCENT;
unsigned long ng_offset_delay = MS_TO_PULSES(DEFAULT_OFFSET_DELAY_MS);
unsigned long ng_debounce_pulse = DEFAULT_DEBOUNCE_PULSE;
unsigned long ng_debounce_percent = DEFAULT_DEBOUNCE_PERCENT;
bool legacy_print_mode = false;  // false for new format, true for legacy format
bool ext_reset_enabled = false;
bool verbose_mode = false;
unsigned long baud_rate = DEFAULT_BAUD_RATE;  // Global baud rate variable

// Add these with other global variables
unsigned long counter_a_b = 0;
const unsigned int MAX_RESTART_COUNTER = 500;
const unsigned int MIN_RESTART_COUNTER = 2;
const unsigned long BASE_REBOOT_THRESHOLD = 1000;
unsigned long last_restart_time = 0;      // Track last restart time
volatile bool ok_interrupt_flag = false;
volatile bool ng_interrupt_flag = false;
volatile unsigned long ok_interrupt_time = 0;  // Changed from ok_interrupt_pulses
volatile unsigned long ng_interrupt_time = 0;  // Changed from ng_interrupt_pulses
int ok_debounce_threshold = 0;  // Pre-calculated threshold
int ng_debounce_threshold = 0;  // Pre-calculated threshold
volatile bool ok_pending_count = false;
volatile bool ng_pending_count = false;
volatile int ok_pending_encoder = 0;
volatile int ng_pending_encoder = 0;
volatile unsigned long last_speed_calc_pulses = 0;
volatile unsigned long last_speed_calc_minute_pulses = 0;
volatile unsigned long last_restart_pulses = 0;
unsigned long last_heartbeat_pulses = 0;
unsigned long heartbeat_interval_pulses = TEN_MS_PULSES * 100;  // Default to slow blink (1s)
bool heartbeat_state = false;

// Add these constants for heartbeat patterns (in pulses)
const unsigned long HEARTBEAT_SLOW = TEN_MS_PULSES * 100;    // 1 second for normal operation
const unsigned long HEARTBEAT_FAST = TEN_MS_PULSES * 20;     // 200ms for warning state
const unsigned long HEARTBEAT_DOUBLE = TEN_MS_PULSES * 10;   // 100ms for double blink
const unsigned long HEARTBEAT_SOLID = 0;      // 0 for solid on

// Add these with other global variables
unsigned long last_heartbeat_millis = 0;  // For millis-based timing

// Add these with other global variables
#define MAX_ENCODER_EVENTS 32
struct EncoderEvent {
  unsigned long scheduled_time;
  int increment;
};
EncoderEvent encoder_events[MAX_ENCODER_EVENTS];
int encoder_head = 0;
int encoder_tail = 0;
int inc = 0;  // Global increment variable

// Add these with other global variables
int ok_encoder_factor = 1;  // Default OK encoder factor
int ng_encoder_factor = 1;  // Default NG encoder factor

// Add this function to calculate thresholds
void updateDebounceThresholds() {
  ok_debounce_threshold = (ok_debounce_pulse * ok_debounce_percent) / 100;
  ng_debounce_threshold = (ng_debounce_pulse * ng_debounce_percent) / 100;
}

// Add these helper functions after the EEPROM definitions

// Write a 4-byte (32-bit) value to EEPROM
void EEPROMWriteULong(int address, unsigned long value) {
  byte byte1 = value & 0xFF;
  byte byte2 = (value >> 8) & 0xFF;
  byte byte3 = (value >> 16) & 0xFF;
  byte byte4 = (value >> 24) & 0xFF;
  EEPROM.write(address, byte1);
  EEPROM.write(address + 1, byte2);
  EEPROM.write(address + 2, byte3);
  EEPROM.write(address + 3, byte4);
}

// Read a 4-byte (32-bit) value from EEPROM
unsigned long EEPROMReadULong(int address) {
  byte byte1 = EEPROM.read(address);
  byte byte2 = EEPROM.read(address + 1);
  byte byte3 = EEPROM.read(address + 2);
  byte byte4 = EEPROM.read(address + 3);
  return ((unsigned long)byte4 << 24) | ((unsigned long)byte3 << 16) | ((unsigned long)byte2 << 8) | byte1;
}

// Initialize EEPROM with default values if empty
void initializeEEPROMIfEmpty() {
  // Check if EEPROM is empty (all bytes are 0xFF)
  bool is_empty = true;
  for (int i = 0; i < 52; i++) {  // Check first 52 bytes (all our settings)
    if (EEPROM.read(i) != 0xFF) {
      is_empty = false;
      break;
    }
  }
  
  if (is_empty) {
    // Write default values
    EEPROMWriteULong(EEPROM_PRINT_MODE, 0);
    EEPROMWriteULong(EEPROM_VERBOSE_MODE, 0);
    EEPROMWriteULong(EEPROM_EXT_RESET_ENABLED, 0);
    EEPROMWriteULong(EEPROM_OK_OFFSET_DELAY, DEFAULT_OFFSET_DELAY_MS);
    EEPROMWriteULong(EEPROM_OK_DEBOUNCE_PULSE, DEFAULT_DEBOUNCE_PULSE);
    EEPROMWriteULong(EEPROM_OK_DEBOUNCE_PERCENT, DEFAULT_DEBOUNCE_PERCENT);
    EEPROMWriteULong(EEPROM_NG_OFFSET_DELAY, DEFAULT_OFFSET_DELAY_MS);
    EEPROMWriteULong(EEPROM_NG_DEBOUNCE_PULSE, DEFAULT_DEBOUNCE_PULSE);
    EEPROMWriteULong(EEPROM_NG_DEBOUNCE_PERCENT, DEFAULT_DEBOUNCE_PERCENT);
    EEPROMWriteULong(EEPROM_DOWNTIME_THRESHOLD, 10);
    EEPROMWriteULong(EEPROM_BAUD_RATE, DEFAULT_BAUD_RATE);
    EEPROMWriteULong(EEPROM_OK_ENCODER_FACTOR, 1);  // Default OK encoder factor
    EEPROMWriteULong(EEPROM_NG_ENCODER_FACTOR, 1);  // Default NG encoder factor
  }
}

void setup() {
  wdt_enable(WDTO_8S);  // 8 second timeout
  
  // Initialize EEPROM with default values if empty
  initializeEEPROMIfEmpty();
  
  // Read baud rate from EEPROM
  baud_rate = EEPROMReadULong(EEPROM_BAUD_RATE);
  if (baud_rate == 0 || baud_rate == 0xFFFFFFFF) {  // If EEPROM is empty or invalid
    baud_rate = DEFAULT_BAUD_RATE;
    EEPROMWriteULong(EEPROM_BAUD_RATE, baud_rate);
  }
  
  // Initialize serial with the correct baud rate
  switch(baud_rate) {
    case 9600:
      Serial.begin(9600);
      break;
    case 19200:
      Serial.begin(19200);
      break;
    case 38400:
      Serial.begin(38400);
      break;
    case 57600:
      Serial.begin(57600);
      break;
    case 115200:
      Serial.begin(115200);
      break;
    default:
      Serial.begin(DEFAULT_BAUD_RATE);  // Fallback to default
      break;
  }
  
  Serial.setTimeout(100); // Add timeout for serial operations
  for(int i = 0; i < 3; i++){
    pinMode(PIN_RPI_DATA_IN[i], INPUT_PULLUP);
    pinMode(PIN_RPI_DATA_OUT[i], OUTPUT);
  }
  
  pinMode(PIN_OK_INPUT, INPUT);
  pinMode(PIN_NG_INPUT, INPUT);
  pinMode(PIN_RPI_ADDRESS, INPUT_PULLUP);
  pinMode(PIN_RPI_SIGNAL, INPUT_PULLUP);

  pinMode(PIN_OK_IDENTIFIER, OUTPUT);
  pinMode(PIN_NG_IDENTIFIER, OUTPUT);
  pinMode(PIN_RPI_RESET, OUTPUT);
  pinMode(PIN_HEARTBEAT_LED, OUTPUT);
  pinMode(PIN_WARNING_LED, OUTPUT);
  digitalWrite(PIN_WARNING_LED, HIGH);
  
  attachInterrupt(digitalPinToInterrupt(PIN_OK_INPUT), count_up_ok, RISING);
  attachInterrupt(digitalPinToInterrupt(PIN_NG_INPUT), count_up_ng, RISING);

  TCCR0B = TCCR0B & B11111000 | B00000001; // for PWM frequency of 62500.00 Hz/ B and U outputs

  // Read settings from EEPROM and convert to pulses
  unsigned long ok_od = EEPROMReadULong(EEPROM_OK_OFFSET_DELAY);
  unsigned long ok_dp = EEPROMReadULong(EEPROM_OK_DEBOUNCE_PULSE);
  unsigned long ok_dl = EEPROMReadULong(EEPROM_OK_DEBOUNCE_PERCENT);
  unsigned long ng_od = EEPROMReadULong(EEPROM_NG_OFFSET_DELAY);
  unsigned long ng_dp = EEPROMReadULong(EEPROM_NG_DEBOUNCE_PULSE);
  unsigned long ng_dl = EEPROMReadULong(EEPROM_NG_DEBOUNCE_PERCENT);
  
  // Validate and set default values if EEPROM values are invalid
  ok_offset_delay = (ok_od == 0 || ok_od == 0xFFFFFFFF) ? MS_TO_PULSES(DEFAULT_OFFSET_DELAY_MS) : MS_TO_PULSES(ok_od);
  ok_debounce_pulse = (ok_dp == 0 || ok_dp == 0xFFFFFFFF) ? DEFAULT_DEBOUNCE_PULSE : ok_dp;
  ok_debounce_percent = (ok_dl == 0 || ok_dl == 0xFFFFFFFF) ? DEFAULT_DEBOUNCE_PERCENT : ok_dl;
  ng_offset_delay = (ng_od == 0 || ng_od == 0xFFFFFFFF) ? MS_TO_PULSES(DEFAULT_OFFSET_DELAY_MS) : MS_TO_PULSES(ng_od);
  ng_debounce_pulse = (ng_dp == 0 || ng_dp == 0xFFFFFFFF) ? DEFAULT_DEBOUNCE_PULSE : ng_dp;
  ng_debounce_percent = (ng_dl == 0 || ng_dl == 0xFFFFFFFF) ? DEFAULT_DEBOUNCE_PERCENT : ng_dl;
  
  // Read mode settings from EEPROM
  unsigned long stored_legacy = EEPROMReadULong(EEPROM_PRINT_MODE);
  unsigned long stored_verbose = EEPROMReadULong(EEPROM_VERBOSE_MODE);
  unsigned long stored_ext_reset = EEPROMReadULong(EEPROM_EXT_RESET_ENABLED);
  
  // Set defaults if EEPROM is empty
  if (stored_legacy == 0 || stored_legacy == 0xFFFFFFFF) {
    legacy_print_mode = false;  // Default to off (new format)
    EEPROMWriteULong(EEPROM_PRINT_MODE, 0);
  } else {
    legacy_print_mode = (stored_legacy == 1);
  }
  
  if (stored_verbose == 0 || stored_verbose == 0xFFFFFFFF) {
    verbose_mode = false;  // Default to off
    EEPROMWriteULong(EEPROM_VERBOSE_MODE, 0);
  } else {
    verbose_mode = (stored_verbose == 1);
  }
  
  if (stored_ext_reset == 0 || stored_ext_reset == 0xFFFFFFFF) {
    ext_reset_enabled = false;  // Default to disabled
    EEPROMWriteULong(EEPROM_EXT_RESET_ENABLED, 0);
  } else {
    ext_reset_enabled = (stored_ext_reset == 1);
  }
  
  downtime_threshold = EEPROMReadULong(EEPROM_DOWNTIME_THRESHOLD);
  if (downtime_threshold == 0) {  // If EEPROM is empty (0), set default value
    downtime_threshold = 10;
    EEPROMWriteULong(EEPROM_DOWNTIME_THRESHOLD, downtime_threshold);
  }

  // Read encoder factors from EEPROM
  ok_encoder_factor = EEPROMReadULong(EEPROM_OK_ENCODER_FACTOR);
  if (ok_encoder_factor == 0xFFFFFFFF) {  // Only set default if EEPROM is empty
    ok_encoder_factor = 1;
    EEPROMWriteULong(EEPROM_OK_ENCODER_FACTOR, ok_encoder_factor);
  }
  
  ng_encoder_factor = EEPROMReadULong(EEPROM_NG_ENCODER_FACTOR);
  if (ng_encoder_factor == 0xFFFFFFFF) {  // Only set default if EEPROM is empty
    ng_encoder_factor = 1;
    EEPROMWriteULong(EEPROM_NG_ENCODER_FACTOR, ng_encoder_factor);
  }

  // Calculate initial thresholds
  updateDebounceThresholds();
}

void loop() {
  // Reset watchdog at the start of each loop
  wdt_reset();
  
  // Get current time once for this loop iteration
  current_time = millis();
  
  handleSerialAndAnalogData();
  
  // Add timeout protection for RPI communication
  if (digitalRead(PIN_RPI_SIGNAL)==LOW){
    last_pi_ping_time = current_time;
    heartbeat_state = !heartbeat_state;
    restart_counter = 1;
    counter_sum_ok_ng = 0;
    get_byte = 0;
    for(int i = 0; i < 3; i++){
      if(digitalRead(PIN_RPI_DATA_IN[i]) == 1)
        bitSet(get_byte, i);
      else
        bitClear(get_byte, i);
    }
    bitClear(get_byte, 3); bitClear(get_byte, 4); bitClear(get_byte, 5); bitClear(get_byte, 6); bitClear(get_byte, 7);
    if(digitalRead(PIN_RPI_ADDRESS)==LOW){
      counter_ng = counter_ng - get_byte;
    }
    else{
      counter_ok = counter_ok - get_byte;
    }
    while (digitalRead(PIN_RPI_SIGNAL)==LOW){
      digitalWrite(PIN_OK_IDENTIFIER, LOW);
      digitalWrite(PIN_NG_IDENTIFIER, LOW);
      handleSerialAndAnalogData();
    }
  }
  else {
    if (counter_ok > 0){
      digitalWrite(PIN_OK_IDENTIFIER, HIGH);
      digitalWrite(PIN_NG_IDENTIFIER, LOW);
      if (counter_ok < 8)
        out_pins_number = counter_ok % 8;
      else if (counter_ok >= 7)
        out_pins_number = 7;
      put_byte_on_pins(out_pins_number);
      delay(5);  
    }

    else if (counter_ng > 0){
      digitalWrite(PIN_OK_IDENTIFIER, LOW);
      digitalWrite(PIN_NG_IDENTIFIER, HIGH);
      if (counter_ng < 16)
        out_pins_number = counter_ng % 8;
      else if (counter_ng >= 7)
        out_pins_number = 7;
      put_byte_on_pins(out_pins_number);
      delay(5);   
    }

    else if (counter_ok + counter_ng <= 0){
      if (battery < 780){
        out_pins_number = int(battery/132) ;
        digitalWrite(PIN_OK_IDENTIFIER, HIGH);
        digitalWrite(PIN_NG_IDENTIFIER, HIGH);
        put_byte_on_pins(out_pins_number);
      }
      else{
        out_pins_number = int(analog/132) ;
        digitalWrite(PIN_OK_IDENTIFIER, LOW);
        digitalWrite(PIN_NG_IDENTIFIER, LOW);
        put_byte_on_pins(out_pins_number);
      }
      delay(5); 
    }

  }  
  
  // Update heartbeat LED with new pattern
  updateHeartbeatLED();
}

void put_byte_on_pins(byte in_byte){
  for(int i = 0; i < 3; i++){
    digitalWrite(PIN_RPI_DATA_OUT[i], bitRead(in_byte, i));
  }
  return;
}

void count_up_ok() {
  if (ok_debounce_pulse == 0) {  // If no debounce delay
    // Handle short debounce directly in interrupt
    if (digitalRead(PIN_OK_INPUT) == HIGH) {
      inc = (digitalRead(PIN_NG_INPUT) == HIGH) ? -1 : 1;
      encoder_events[encoder_head] = {current_time + ok_offset_delay, inc * ok_encoder_factor};
      encoder_head = (encoder_head + 1) % MAX_ENCODER_EVENTS;
      counter_ok++;
    }
  } else {
    // For longer debounces, set flag for main loop
    ok_interrupt_flag = true;
    ok_interrupt_time = millis();
  }
}

void count_up_ng() {
  if (ng_debounce_pulse == 0) {  // If no debounce delay
    // Handle short debounce directly in interrupt
    if (digitalRead(PIN_NG_INPUT) == HIGH) {
      inc = (digitalRead(PIN_OK_INPUT) == HIGH) ? 1 : -1;
      encoder_events[encoder_head] = {current_time + ng_offset_delay, inc * ng_encoder_factor};
      encoder_head = (encoder_head + 1) % MAX_ENCODER_EVENTS;
      counter_ng++;
    }
  } else {
    // For longer debounces, set flag for main loop
    ng_interrupt_flag = true;
    ng_interrupt_time = millis();
  }
}

void process_encoder_events() {
  while (encoder_tail != encoder_head && encoder_events[encoder_tail].scheduled_time <= current_time) {
    encoder_counter += encoder_events[encoder_tail].increment;
    encoder_tail = (encoder_tail + 1) % MAX_ENCODER_EVENTS;
  }
}
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

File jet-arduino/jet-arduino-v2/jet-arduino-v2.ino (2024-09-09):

#include <avr/wdt.h>

const byte input_a = 2; // OK
const byte input_b = 3; // NG
const byte piPin = 11; // RPI Signal to Arduino
const byte a_or_b = 18; // RPI Address to Arduino
const byte Warning = 13; // Warning LED Panel
const byte DataCapture = 10; // Link LED Panel
const byte rpi_off = 12; // To force restart RPI by Arduino
const byte a_identifier = 8; // RPI Address to Arduino
const byte b_identifier = 9; // RPI Address to Arduino

byte input_pins[4] = {
  14, 15, 16, 17
}; // RPI data pins to Arduino

byte output_pins[4] = {
  4, 5, 6, 7
}; // Arduino data pins to RPI

boolean old_a;
boolean old_b;
long counter_a = 0;
long counter_b = 0;
long encoder_counter = 0; // need 100nf cap instead of 1uf in optocouplers
unsigned int battery;
unsigned int c = 0; 
unsigned int e = 0; // extra analog read on A7
unsigned int i = 0; // counter for serial print
unsigned int counter_rpi_reboot = 100;
unsigned int restart_counter = 1;
long counter_a_b = 0;
unsigned long elapsed_speed=100;
volatile long a_capture_time=millis();
volatile long b_capture_time=millis();
unsigned long now_millis;

byte get_byte;
byte out_pins_number;

void(* resetFunc) (void) = 0;

void setup() {
  wdt_enable( WDTO_8S);
  Serial.begin(9600); 
  for(int i = 0; i < 4; i++){
    pinMode(input_pins[i], INPUT_PULLUP);
    pinMode(output_pins[i],OUTPUT);
  }
  
  pinMode(input_a, INPUT);
  pinMode(input_b, INPUT);
  pinMode(a_or_b, INPUT_PULLUP);
  pinMode(piPin, INPUT_PULLUP);

  pinMode(a_identifier, OUTPUT);
  pinMode(b_identifier, OUTPUT);
  pinMode(rpi_off, OUTPUT);
  pinMode(DataCapture, OUTPUT);
  pinMode(Warning, OUTPUT);
  
  attachInterrupt(digitalPinToInterrupt(input_a), count_up_a, RISING);
  attachInterrupt(digitalPinToInterrupt(input_b), count_up_b, RISING);
}

void loop() {
  // get analog data
  c = analogRead(A5);
  battery = analogRead(A6);  
  e = analogRead(A7);
  digitalWrite(DataCapture, LOW);
  i++;
  if ( i > 500){
    Serial.println(String(encoder_counter) + "," + String(counter_a) + "," + String(counter_b) + "," + String(c) + "," + String(e) + "," + String(battery/10 - 2) + "," + String(elapsed_speed) + "," + String(restart_counter));
    i = 0;
  }
  // check if RPI is signaling the ARDUINO
  if (digitalRead(piPin)==LOW){
    digitalWrite(DataCapture, HIGH);
    get_byte = 0;
    for(int i = 0; i < 4; i++){
      if(digitalRead(input_pins[i]) == 1)
        bitSet(get_byte, i);
      else
        bitClear(get_byte, i);
    }
    bitClear(get_byte, 4); bitClear(get_byte, 5); bitClear(get_byte, 6); bitClear(get_byte, 7);
    if(digitalRead(a_or_b)==LOW){
      counter_b = counter_b - get_byte;
    }
    else{
      counter_a = counter_a - get_byte;
    }
    while (digitalRead(piPin)==LOW){
      digitalWrite(a_identifier, LOW);
      digitalWrite(b_identifier, LOW);
      delay(5);
      wdt_reset();
      
    }
  }
  else {
    if (counter_a > 0){
      digitalWrite(a_identifier, HIGH);
      digitalWrite(b_identifier, LOW);
      if (counter_a < 16)
        out_pins_number = counter_a % 16;
      else if (counter_a >= 16)
        out_pins_number = 15;
      put_byte_on_pins(out_pins_number);
      delay(5);  
    }

    else if (counter_b > 0){
      digitalWrite(a_identifier, LOW);
      digitalWrite(b_identifier, HIGH);
      if (counter_b < 16)
        out_pins_number = counter_b % 16;
      else if (counter_b >= 16)
        out_pins_number = 15;
      put_byte_on_pins(out_pins_number);
      delay(5);   
    }

    else if (counter_a + counter_b <= 0){
      if (battery < 780){
        out_pins_number = int(battery/66) ;
        digitalWrite(a_identifier, HIGH);
        digitalWrite(b_identifier, HIGH);
        put_byte_on_pins(out_pins_number);
      }
      else{
        out_pins_number = int(c/66) ;
        digitalWrite(a_identifier, LOW);
        digitalWrite(b_identifier, LOW);
        put_byte_on_pins(out_pins_number);
      }
      delay(5); 
    }

  }
  
  now_millis = millis();
  elapsed_speed =  long(50/(now_millis - a_capture_time) + 50/(now_millis - b_capture_time) + elapsed_speed*999/1000) ;
  counter_rpi_reboot = (elapsed_speed+1000)*restart_counter;
  counter_a_b = abs(counter_a + counter_b);
  if ( (battery > 100 and battery < 800) or counter_a_b > counter_rpi_reboot/2)
    digitalWrite(Warning, HIGH);
  else
    digitalWrite(Warning, LOW);

      
  if (counter_a_b > counter_rpi_reboot){
    digitalWrite(rpi_off, HIGH);
    delay(1000);
    digitalWrite(rpi_off, LOW);
    if (restart_counter < 500){
        restart_counter = restart_counter * 2;
        counter_rpi_reboot = (elapsed_speed+1000)*restart_counter;
      }
    else{
        restart_counter = 499;
        resetFunc();
        }
    delay(1000);
  }
  
  if ((counter_a_b < counter_rpi_reboot/100) and (restart_counter > 2)){
    restart_counter = restart_counter/2;
  }
  
  delay(1);
  wdt_reset();
}

void put_byte_on_pins(byte in_byte){
  for(int i = 0; i < 4; i++){
      digitalWrite(output_pins[i], bitRead (in_byte, i));
    }
  return;
}

void count_up_a(){
  int j = 0;  
  for(int i = 0; i < 3; i++){
    delay(1);
    if (digitalRead(input_a) == HIGH){
      j++;
    }
  }
  if (j > 2){
    a_capture_time = millis();
    counter_a++;
    if (digitalRead(input_b) == HIGH)
      encoder_counter++;
    else
      encoder_counter--;  
  }  
  return;
}

void count_up_b(){
  int j = 0;  
  for(int i = 0; i < 3; i++){
    delay(1);
    if (digitalRead(input_b) == HIGH){
      j++;
    }
  }
  if (j > 2){
    b_capture_time = millis();
    counter_b++;
    if (digitalRead(input_a) == HIGH)
      encoder_counter--;
    else
      encoder_counter++;
  }  
  return;
}

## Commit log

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2022-09-10 debug: interupt doesn't work well
    [gpio.py]
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2022-10-19 feat: add pcb
    [Monitait.PrjPcb, Monitait.SchDoc]
2022-10-27 debug: change the arduino initial value to 0
2022-12-12 feat: add redis as a broker
    [gpio-rpi.py, main.py]
2022-12-13 debug: add failed requests attempts
    [gpio-rpi.py]
2023-12-03 Jet printing side
    [jet.dxf, monitait_engrave_watcher_jet_logo.dxf]
2023-12-03 PCB version 2
    [Monitait_V2.PrjPcb, Monitait_V2.SchDoc]
2023-12-07 debug: change arduino battery and adc
2023-12-07 debug: remove extra prints
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2023-12-09 debug: no print clause
2023-12-10 feat: reboot in case of emergency
    [main.py, watcher-black.ino]
2024-01-02 Added capacity, indicator, and buzzer
    [Monitait_V2.PrjPcb, Monitait_V2.SchDoc]
2024-01-02 Added polygon
    [Monitait_V2.SchDoc]
2024-01-02 Fixed a pin connection to GND polygon
    [Monitait_V2.SchDoc]
2024-01-02 A bad track was corrected
2024-01-03 debug: counter overflow issues
    [watcher-black.ino]
2024-01-08 fix: add printing layout
2024-01-08 Added 6 pin dip swithch
    [Monitait_V2.PrjPcb, Monitait_V2.SchDoc]
2024-01-08 R21 is removed
    [Monitait_V2.SchDoc]
2024-01-08 debug: add v2.1 side layout
    [jet.dxf, watcher-jet-v2.1-side-layout.dxf]
2024-01-10 feat: printing layout v2.1
    [watcher-jet-v2.1-side-layout.dxf]
2024-01-14 debug: add handler to request to retry
    [monitait_engrave_watcher_jet_logo.dxf]
2024-01-14 debug: reset arduino on ceiling
    [main.py]
2024-01-18 Added the resistors between AR and RASp (Sch only)
    [Monitait_V2.SchDoc]
2024-01-18 Added resistors, modified notations and tracks
2024-01-18 Added additional GND via
2024-01-18 R5 pin wire changed
    [Monitait_V2.SchDoc]
2024-01-18 Increased a track width
2024-01-29 feat: add v13 corel file for the printing
2024-01-31 :sparkle: arduino v2.2, change warning and relay pins
2024-02-02 changed the Buzzer circuit
    [Monitait_V2.SchDoc]
2024-02-02 Changed timer 11.1 pins to sw12
    [Monitait_V2.SchDoc]
2024-02-02 Added aditional resistors
    [Monitait_V2.SchDoc]
2024-02-02 D1 is removed
    [Monitait_V2.SchDoc]
2024-02-02 SW11 track is removed
    [Monitait_V2.SchDoc]
2024-02-02 The resistors are changed
    [Monitait_V2.SchDoc]
2024-02-02 Dimensions of L1 are corrcted
    [Monitait_V2.PrjPcb]
2024-02-02 10uf capacitor is changed
    [Monitait_V2.SchDoc]
2024-02-02 Added elements to the PCB
2024-02-02 Removed additional capcaitor
    [Monitait_V2.SchDoc]
2024-02-03 All elements placed on the PCB
2024-02-03 The new resistors have been wired
2024-02-03 additional 11.1v tracks are removed
2024-02-03 The buzzer 12V track is placed
2024-02-03 The track of remainded resistors is placed
2024-02-04 Tracked some GND vias
2024-02-04 Connected the capacitor GND pins
2024-02-04 added aditional GND via
2024-02-04 GND vias connected to each other
2024-02-04 D1 track is changed
    [Monitait_V2.SchDoc]
2024-02-04 ARDUINO GND pins connected
2024-02-04 The width of SW11 track is increased
2024-02-04 some small change
    [Monitait_V2.SchDoc]
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2024-03-26 The charger tracks are modified
    [Monitait_V2.PrjPcb]
2024-03-26 Added the resistors between Ar and Rasp
    [Monitait_V2.SchDoc]
2024-03-26 Added aditional resistors and capacitros
    [Monitait_V2.SchDoc]
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2024-03-26 Some small changes
    [Monitait_V2.SchDoc]
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2024-03-26 The additional capacitors removed
    [Monitait_V2.SchDoc]
2024-03-26 Added a capacitor for raspb
    [Monitait_V2.SchDoc]
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2024-03-27 Added aditional resistors for A6
    [Monitait_V2.SchDoc]
2024-03-27 Change the elements positions
    [Monitait_V2.SchDoc]
2024-03-27 added male PCB connector
    [Monitait_V2.SchDoc]
2024-03-27 added the elemets annotations
    [Monitait_V2.SchDoc]
2024-03-27 changed the connectors model
    [Monitait_V2.SchDoc]
2024-03-27 Added the resistors and connectors to the PCB
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2024-03-28 A connector name changed
    [Monitait_V2.SchDoc]
2024-03-28 C4 changed to 1000uF
    [Monitait_V2.SchDoc]
2024-03-28 COP connector
    [COP_connector.PcbDoc]
2024-03-28 Added some notations
    [COP_connector.PcbDoc]
2024-03-29 SCL pin connected to the header
    [Monitait_V2.PrjPcb, Monitait_V2.SchDoc]
2024-03-30 Pad positions changed
    [COP_connector.PcbDoc]
2024-03-30 Pad size increased
    [COP_connector.PcbDoc]
2024-03-30 added top solder mask
    [COP_connector.PcbDoc]
2024-03-30 Solder layer size increased
    [COP_connector.PcbDoc]
2024-03-30 Solder mask layer changed to bottom
    [COP_connector.PcbDoc]
2024-03-30 The solder mask removed
    [COP_connector.PcbDoc]
2024-03-30 Added 2-pin connector
    [COP_connector.PcbDoc]
2024-03-30 :sparkle: organize
    [1803332.SLDPRT, 1803332.stp, 3 Battery Holder With Batteries.SLDPRT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]
2024-03-30 feat: organize
    [Monitait.PrjPcb, Monitait.SchDoc]
2024-03-30 Added aditional resistance and the date updated
    [Monitait_V2.SchDoc]
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2024-04-24 debug: problem with image path
    [main.py]
2024-04-25 feat: down/up wlan interface in case of disconnect
2024-04-25 feat: store image path in shorter format
    [main.py]
2024-04-25 feat: preventing of flood fill of err_msg
    [main.py]
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2024-05-14 fix connection try catch
    [dev_main.py]
2024-05-14 fix starter threads
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2024-05-16 fix init arduino
2024-05-16 fix DB module instance
    [dev_main.py]
2024-05-16 fix log prints
2024-05-16 fix counter image and live siganl
    [dev_main.py]
2024-05-16 fix sqlite multi thread
    [dev_main.py]
2024-05-16 fix log watcher update
    [dev_main.py]
2024-05-16 fix health check for camera
    [dev_main.py]
2024-05-16 fix remove extra log print
    [dev_main.py]
2024-05-18 fix image capture interval
    [dev_main.py]
2024-05-18 fix local variable error
    [dev_main.py]
2024-05-18 fix release camera
2024-06-23 feat: connecting to serial1 if serial0 connection failed
    [main.py]
2024-07-18 feat: update PCB files
    [COP_connector.PcbDoc, Monitait.PrjPcb, Monitait.SchDoc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]
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2024-07-19 test: buzz and print
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2024-08-03 feat: add 2D print files
    [1803332.SLDPRT, 1803332.stp, 3 Battery Holder With Batteries.SLDPRT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]
2024-08-09 debug; avoid infinite reset arduino
    [jet-arduino.ino]
2024-08-11 test encoder value to merge both fabriqc and watcherJet
2024-08-13 feat: 2D version
    [watcher-jet-back.dxf, watcher-jet-front.dxf]
2024-08-20 debug: adjust 2d print
    [watcher-jet-back.dxf, watcher-jet-front.dxf]
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2024-08-30 feat: add dip switch options. camera and scanner
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2024-09-13 feat: change priphery to gpiozero for watcher pcb version2
2024-09-17 debug: fix serial encoder var and restart counting
    [main.py]
2024-09-17 debug: fix encoder value into serial
    [jet-arduino.ino]
2024-11-09 fix: read ttyusb by os
    [main.py]
2024-11-10 fix: reset to latest version
    [jet-arduino.ino]
2024-11-15 fix: get back serial print to the original
    [jet-arduino.ino]
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2025-03-30 debug: semantic issue of sts
    [jet-arduino.ino]
2025-05-05 add the size
    [Watcher JET Assy.SLDDRW]
2025-05-08 refactor: reorganize pin definitions and enhance debounce handling for OK/NG signals
2025-05-19 feat: add encoder factor management and improve event processing for OK/NG signals
2025-05-19 fix: ensure encoder factors are set as integers to prevent invalid values
    [jet-arduino.ino]
2025-05-19 fix: update EEPROM read logic to only set default encoder factors when EEPROM is empty
    [jet-arduino.ino]
2025-05-24 debug: fix the speed ppm for downtime measuring
    [jet-arduino.ino]
